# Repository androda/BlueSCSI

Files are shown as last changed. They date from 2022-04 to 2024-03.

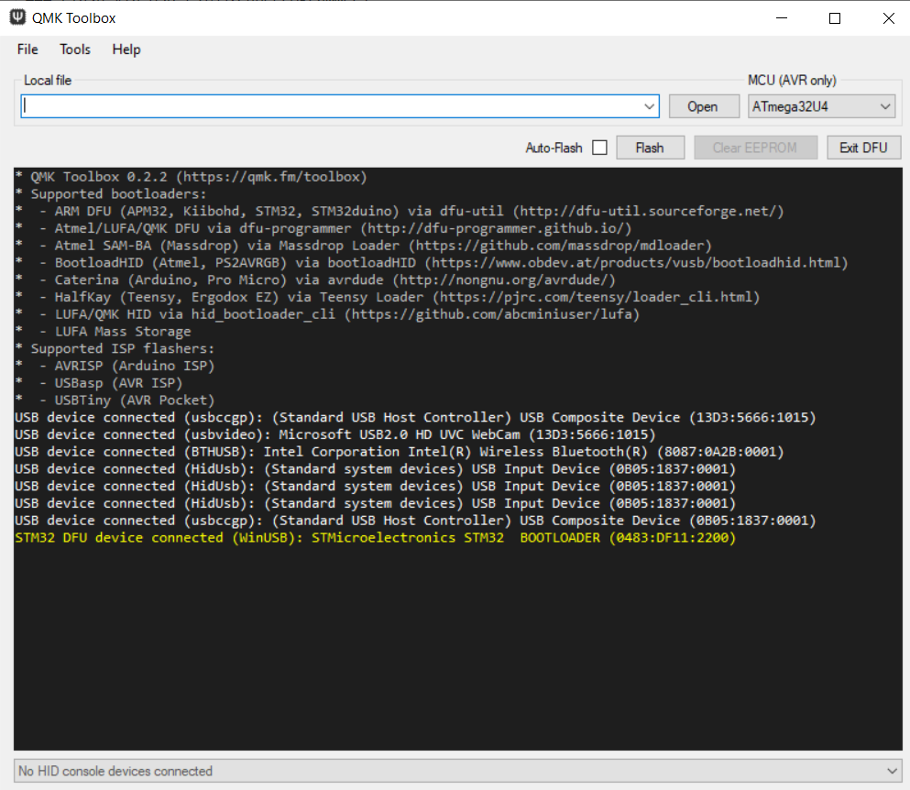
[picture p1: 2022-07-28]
docs/Images/qmk_toolbox_STM32_Detected.PNG

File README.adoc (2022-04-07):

# F4 BlueSCSI
:toc: macro

`F4 BlueSCSI`, ported by https://github.com/androda[androda], is a fork of `BlueSCSI` which targets the STM32F401 and STM32F411 microcontrollers.

toc::[]

### Lineage
F4 BlueSCSI, BlueSCSI, and ArdSCSino are hardware that reproduces SCSI devices (hard disks) with an STM32 Microcontroller.

`BlueSCSI` was created by https://github.com/erichelgeson[erichelgeson]

`ArdSCSino-stm32` was created by https://github.com/ztto/ArdSCSino-stm32[ztto], and is the STM32 version of `ArdSCSino`

`ArdSCSino` was created by https://twitter.com/h_koma2[Tambo (TNB Seisakusho)]

## Discussion
Join us in #bluescsi on https://discord.gg/GKcvtgU7P9[Discord].

## Compatibility and Performance
https://github.com/androda/F4_BlueSCSI/wiki/System-Compatibility-and-Performance[Compatibility and Performance]

## Assembly
Assembly instructions are generally found on my separate site, here: https://androda.work/kit-assembly/
These aren't really assembly instructions either, mostly pictures of the assembled design with tips on which way things should be facing.

## Usage
https://github.com/erichelgeson/BlueSCSI/wiki/Usage[Usage] is intended to be the same as the parent project and will be kept in sync until the blue pill module's flash is all used.  Then F4 will start to diverge.

### Termination
Termination enable / disable is handled differently per board style.  See the instructions for each PCB design.

## Firmware Updates
https://github.com/androda/F4_BlueSCSI/wiki/Flashing-Firmware-Updates[Flashing Firmware Updates]

## Troubleshooting
(to be completed, currently similar to the parent repo - but there are no jumpers on these dev modules.)
https://github.com/erichelgeson/BlueSCSI/wiki/Troubleshooting

## Hardware Versions
Generally speaking, hardware versions follow a naming scheme.

Variant.Maker.Style.Version

For example: {F4.TbA.D.V1}

This is an F4 model from Tech by Androda, D is for Desktop and V1 means first revision.

## Development (Advanced, annoying to set up)
https://github.com/androda/F4_BlueSCSI/tree/main/docs/Dev_Instructions[Dev Instructions]

## Notes

### Building the Code
- Build experience is unfortunately complex due to Maple's STM32F4 compatibility issues

### Making Gerbers for JLCPCB
https://support.jlcpcb.com/article/44-how-to-export-kicad-pcb-to-gerber-files

BlueSCSI(TM) - Eric Helgeson - All rights reserved. - Used with permission

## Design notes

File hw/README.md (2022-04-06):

# F4 and F4Lite Hardware License

* © 2021 - 2022 Tech by Androda, LLC
* All hardware design files, design artifacts, and in general all files provided in the hardware section (/hw/ and below) are licensed Attribution-NonCommercial-ShareAlike 4.0 International (CC BY-NC-SA 4.0)
* https://creativecommons.org/licenses/by-nc-sa/4.0/legalcode

These files are provided AS-IS with no warranty of any kind to the maximum extent allowed by law.

License Explanation:

Hardware:
This license means that you can have these designs produced by the PCB maker of your choice, for your own personal use.
You, the licensee, are not permitted to re-sell the PCBs which are produced using these design and production files.  They are not licensed for sale of any kind, regardless of whether you have 'spares' left over.  Selling them 'at cost' or 'below cost' is also a violation of the license, because those are sales too.

3D Printable Files:
This license allows you to print these printable files yourself, or have them printed for you, for your own personal use.  You, the licensee, are not permitted to re-sell the printed parts which are produced under this license.  They are not licensed for sale of any kind, regardless of whether you made (or had made) more than you needed.  A sale 'at cost' or 'below cost' is still a sale and is a license violation.

All other files:
Seriously, why would you try to sell these?

Alternate Licensing available:
If you would like to produce these hardware designs and printed parts for sale, you are encouraged to contact Tech by Androda, LLC to arrange alternate licensing.  https://androda.work/about/

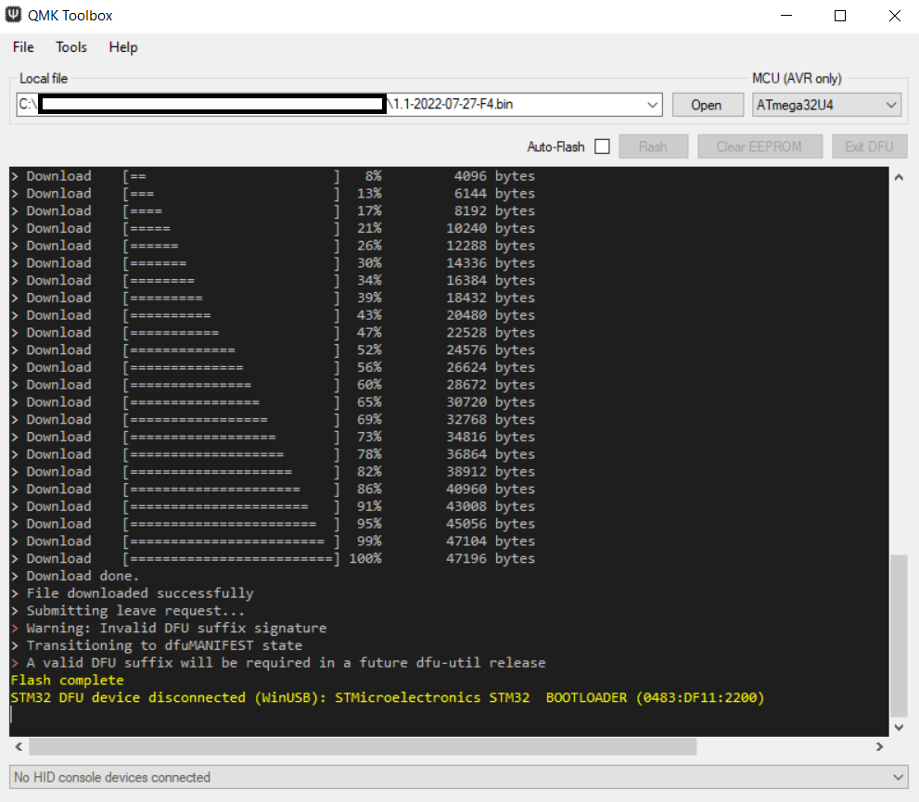
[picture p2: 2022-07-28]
docs/Images/qmk_toolbox_flash_successful.PNG

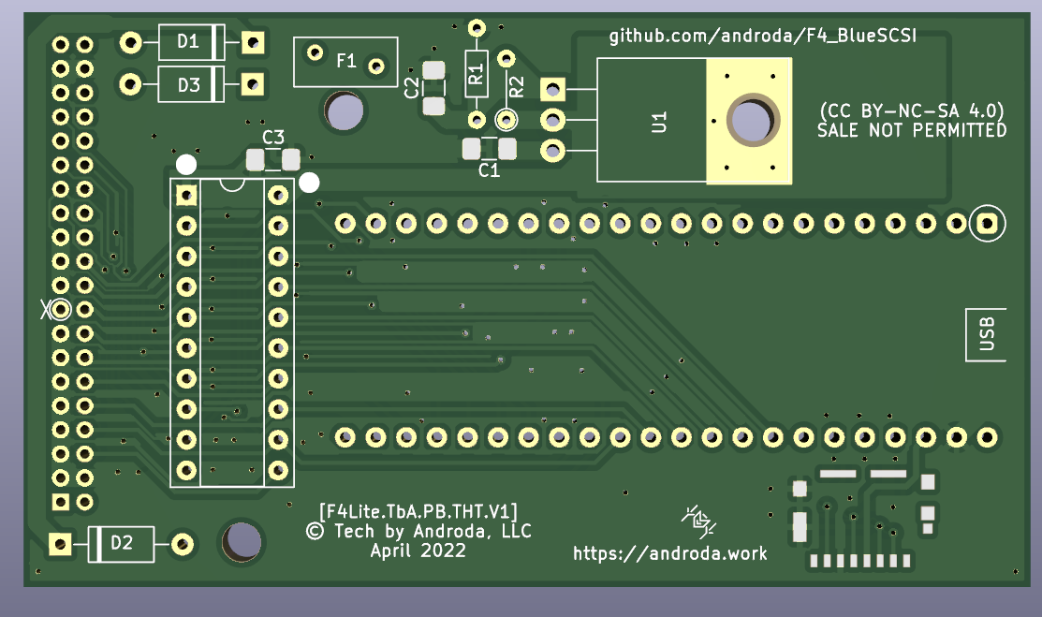
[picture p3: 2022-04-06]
hw/PowerBook/PowerBook_F4Lite_THTV1/TopOfPCB.PNG

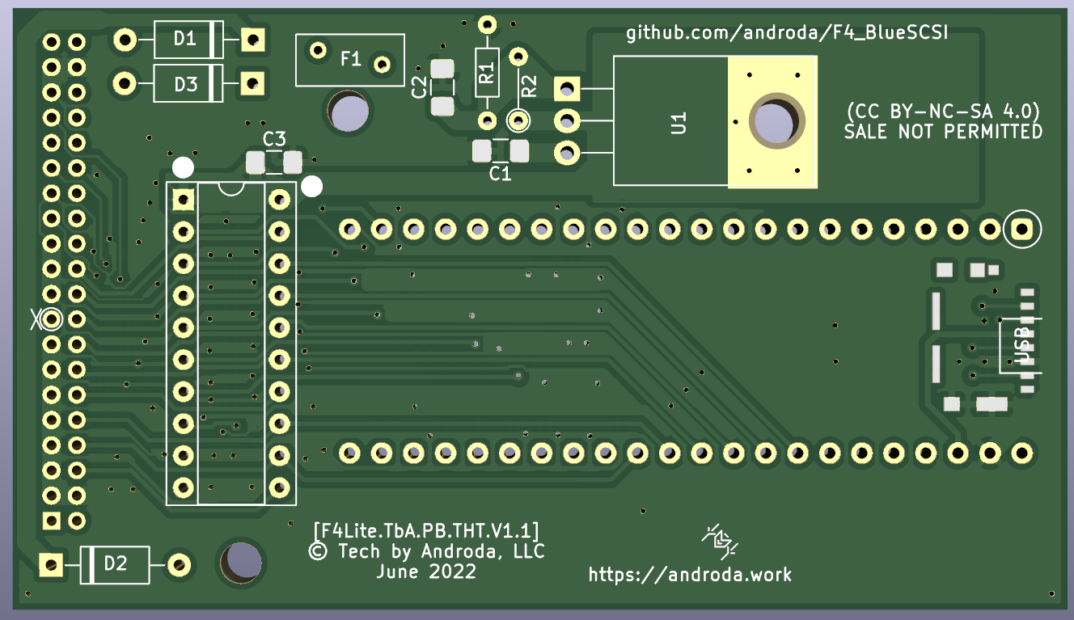
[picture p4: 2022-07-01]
hw/PowerBook/PowerBook_F4Lite_THTV1.1/TopOfPCB.PNG

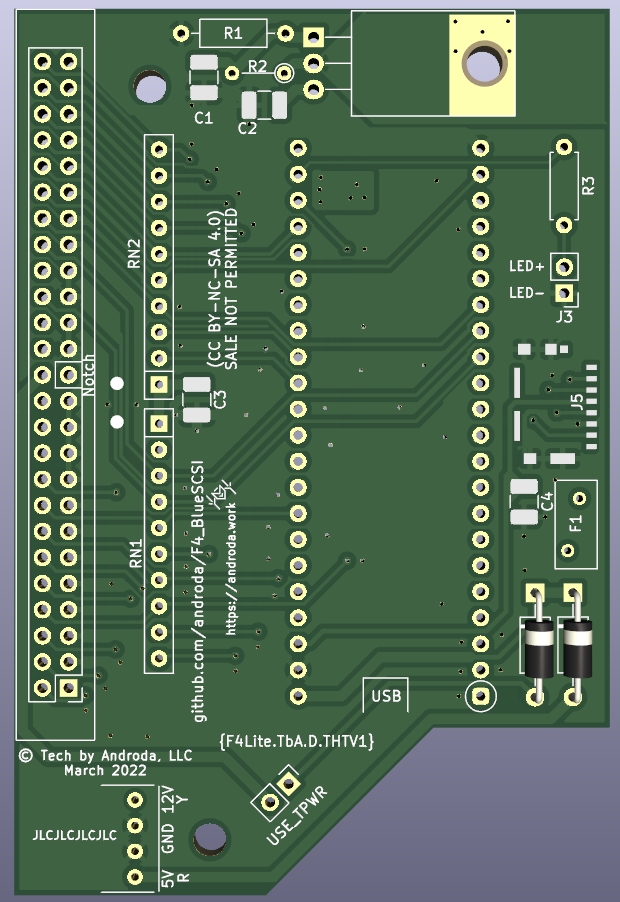
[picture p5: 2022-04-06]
hw/Desktop_50Pin/F4Lite_THTV1/TopofPCB.PNG

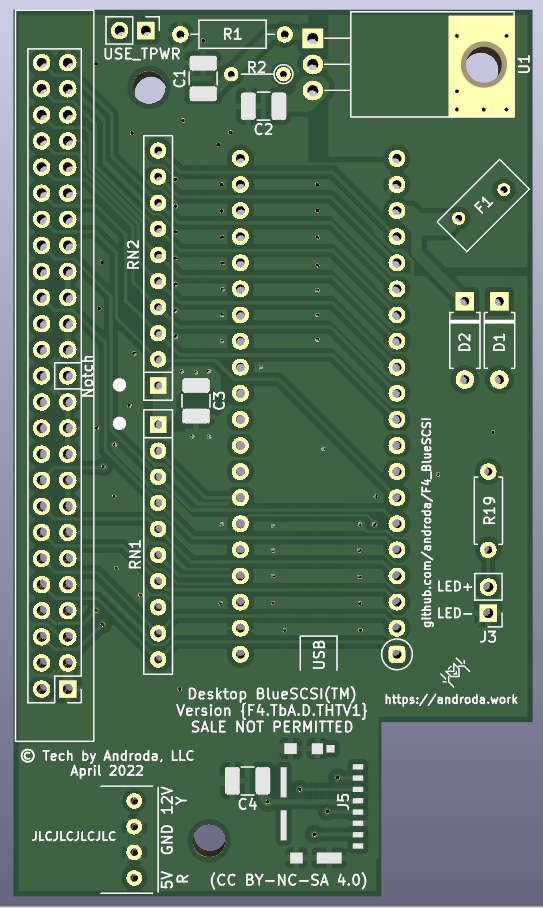
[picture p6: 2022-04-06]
hw/Desktop_50Pin/F4_THTV1/TopOfPCB.PNG

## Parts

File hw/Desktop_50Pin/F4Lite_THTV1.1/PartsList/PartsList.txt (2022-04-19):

Parts List for F4Lite THT V1.1

Through-hole parts:

Some 2.54mm header strip (optional, could hard wire 'USE_TPWR' jumper and hard wire the LED)
A 2.54mm jumper (If using header strip for the USE_TPWR jumper, this is required)
0ZRR0050FF1E fuse, x1
SB130-T diodes, x2 (any schottky with 800mA+ rating ought to be fine)
LD1117V adjustable linear regulator x1
MFS1/4DCT52R1200F 120 ohm resistor for position R2, x1
MFR-25FBF52-154R 154 ohm resistor for position R1, x1
^  These resistor *values* are non-negotiable, but their physical sizing can differ
470 Ohm resistor for LED, x1  (bought on eBay, precision doesn't matter)
4610X-101-111LF 110 ohm resistor network, x2
^ Can grab some 20 pin DIP chip sockets and chop in half to use as sockets for the resistor nets
Berg Floppy connector, TE Connectivity 171826-4
50 pin SCSI connector, or male 2x25 2.54mm header: Must be straight-out only
^ For the SCSI connector, there are a ton of options:
* 3M 30350-6002HB (straight)
* https://www.aliexpress.com/item/4000284180928.html

Microcontroller Module:
STM32F401 "Green Pill", this is the one you're looking for: https://stm32-base.org/boards/STM32F401CCU6-STM32-Mini-F401
* Search Amazon or eBay for "STM32F401"
* https://www.aliexpress.com/item/1005001639712812.html

Surface-Mount parts:
Three 1206 size 22uF capacitors, 10+ volt rating (higher voltage rating is better, I used 25V)
Molex 105162-0001 MicroSD Card Slot
Four 0805 size 4.7uF capacitors, 10+ volt rating (higher voltage rating is better, I do 16+)
* Generally speaking any value from 0.1uF to 4.7uF is fine for these.  They are just for extra decoupling.

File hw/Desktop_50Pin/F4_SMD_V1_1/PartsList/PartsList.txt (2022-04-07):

Parts List for F4 SMD V1.1

Through-hole parts:
Some 2.54mm header strip (optional, could hard wire 'USE_TPWR' jumper and hard wire the LED)
A 2.54mm jumper (If using header strip for the USE_TPWR jumper, this is required)
Berg Floppy connector, TE Connectivity 171826-4
50 pin SCSI connector, male 2x25 2.54mm header - can be straight-out or right-angle as long as the notch is in the right place.
^ For the SCSI connector, there are a ton of options:
* 3M 30350-6002HB (straight)
* 3M 30350-5002HB (right angle)
* https://www.aliexpress.com/item/4000284180928.html

Microcontroller Module:
STM32F411 "Black Pill" (note that there are two versions of this design, one using an F411 and one with an F401 - F411 is the correct one)
This is the one you want: https://stm32-base.org/boards/STM32F401CEU6-WeAct-Black-Pill-V3.0
^ Note that this page says it's an F401, but the official store (aliexpress link below) shows an F411.
* Search Amazon or eBay for "STM32F411" 
* https://www.aliexpress.com/item/1005001456186625.html

Surface-Mount parts:
Two 1206 size 22uF capacitors, 10+ volt rating (higher voltage rating is better, I used 25V)
One 0805 size 4.8uF capacitor, similar voltage rating as ^
Three SOD-123F Schottky Diodes, 800+ mA continuous current rating
Two 0805 size 500mA-hold rated PTC Fuses
Eighteen 0603 size 110 ohm resistors
One 2.85v rated 1117 linear regulator in SOT-223 package
Two SN74CBTD3861DBQR bus switches
Molex 105162-0001 MicroSD Card Slot

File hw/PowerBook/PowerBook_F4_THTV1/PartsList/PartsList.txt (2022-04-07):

Parts List for PowerBook F4 THT V1

Through-hole parts:

0ZRR0050FF1E fuse, x1
SB130-T diodes, x3 (any schottky with 800mA+ rating ought to be fine)
LD1117V adjustable linear regulator x1
MFS1/4DCT52R1200F 120 ohm resistor for position R2, x1
MFR-25FBF52-154R 154 ohm resistor for position R1, x1
^  These resistor *values* are non-negotiable, but their physical sizing can differ
4610X-101-102LF 1000 ohm resistor network, x2
^ Can grab some 20 pin DIP chip sockets and chop in half to use as sockets for the resistor nets
40 Pin PowerBook SCSI connector
* Harwin M22-2042005
* 2x20 2.0mm two-row connectors have been hard to find.  But 2x40 are somewhat common, and can be cut in half with an exacto knife.
* https://www.aliexpress.com/item/2051375493.html

Microcontroller Module:
STM32F411 "Black Pill" (note that there are two versions of this design, one using an F411 and one with an F401 - F411 is the correct one)
This is the one you want: https://stm32-base.org/boards/STM32F401CEU6-WeAct-Black-Pill-V3.0
^ Note that this page says it's an F401, but the official store (aliexpress link below) shows an F411.
* Search Amazon or eBay for "STM32F411" 
* https://www.aliexpress.com/item/1005001456186625.html

Surface-Mount parts:
Three 1206 size 22uF capacitors, 10+ volt rating (higher voltage rating is better, I used 25V)
Molex 105162-0001 MicroSD Card Slot

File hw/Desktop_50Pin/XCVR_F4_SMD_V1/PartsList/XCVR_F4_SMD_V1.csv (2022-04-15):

Id | Designator | Quantity | Part
1 | J3 | 1 | SCSI 50 Pin Connector, 2x25 2.54mm spacing male header
2 | R6,R4,R5,R10,R7,R8,R1,R11,R9,R3,R2,R18,R17,R16,R15,R14,R13,R12 | 18 | 0603 SMD Resistor, 110 Ohm
3 | J4 | 1 | Berg Floppy Connector, TE Connectivity 171826-4
4 | C1,C2 | 2 | 1206 SMD 22uF Capacitor, 10v+
5 | U3 | 1 | AMS1117-2.85
6 | U1, U2 | 2 | SN74CBTD3861DBQR
7 | F1 | 1 | 0ZRR0050FF1E
8 | C3,C9,C10,C11,C12 | 5 | 0805 SMD 4.7uF Capacitor, 10v+
10 | U4,U5 | 2 | SN74LVT162245ADGGR
11 | C4,C5,C6,C7,C8 | 5 | 0805 SMD 0.1uF Capacitor, 10v+
12 | R19 | 1 | 0805 SMD 10k resistor
13 | J1 | 1 | 1x2 male header
14 | R21 | 1 | 0805 SMD Resistor, 470 Ohm
15 | SD1 | 1 | SOFNG SD-001
16 | D1,D2 | 2 | SS14 SMA Diode
17 | J2 | 1 | 1x3 male header
18 | U6 | 1 | Black STM32F411 Dev Board

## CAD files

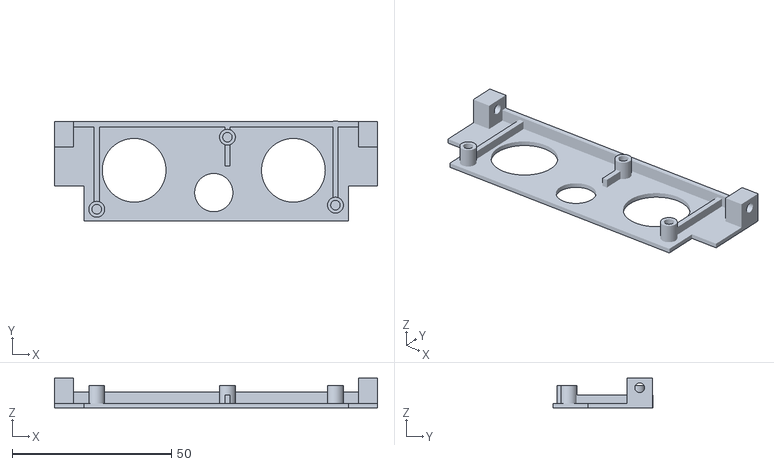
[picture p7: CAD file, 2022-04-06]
hw/Desktop_50Pin/F4_SMD_V1_1/F4_V1_DesktopMountingBracket.stl
101.4 x 31.5 x 9.40

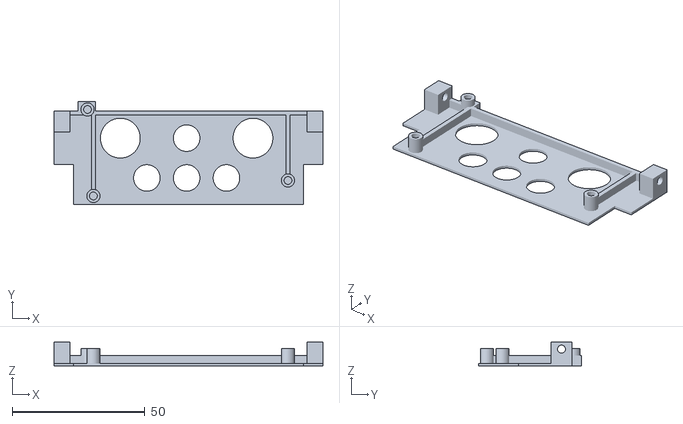
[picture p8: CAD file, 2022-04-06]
hw/Desktop_50Pin/F4_THTV1/MountingBracket.stl
101.4 x 38.8 x 9.00

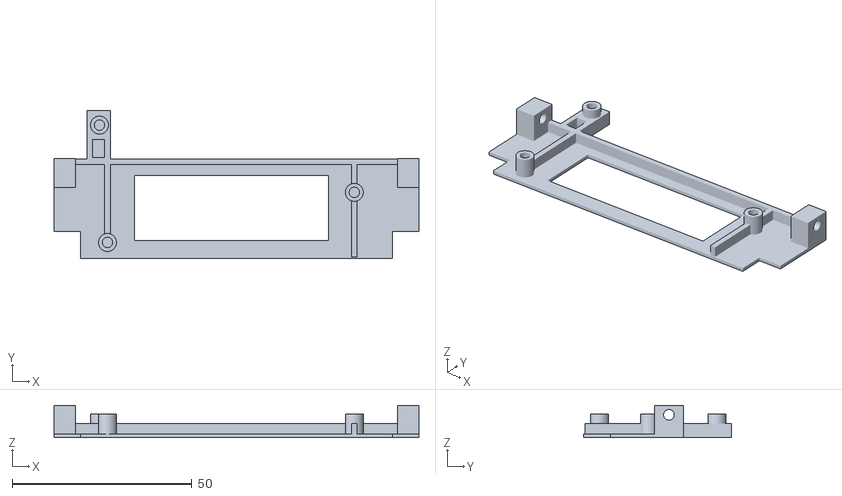
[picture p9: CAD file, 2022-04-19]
hw/Desktop_50Pin/F4Lite_THTV1.1/MountingBracket.stl
101.4 x 41.0 x 9.00

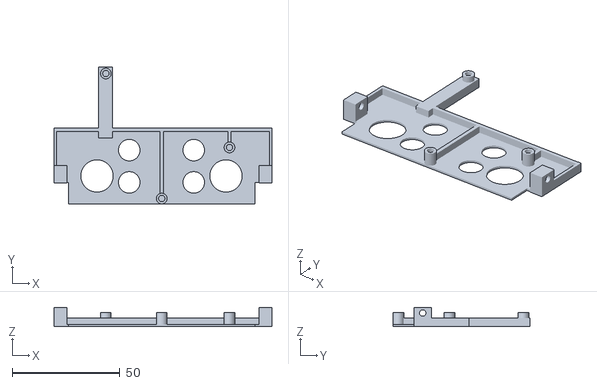
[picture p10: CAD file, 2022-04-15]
hw/Desktop_50Pin/XCVR_F4_SMD_V1/MountingBracket.stl
101.4 x 63.6 x 9.00

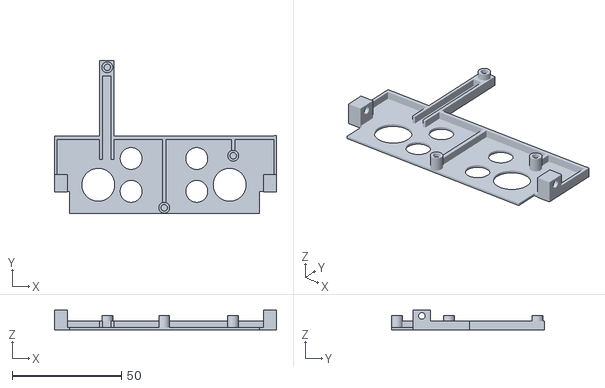
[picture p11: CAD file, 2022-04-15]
hw/Desktop_50Pin/XCVR_F4Lite_SMD_V1/MountingBracket.stl
101.4 x 69.7 x 9.00

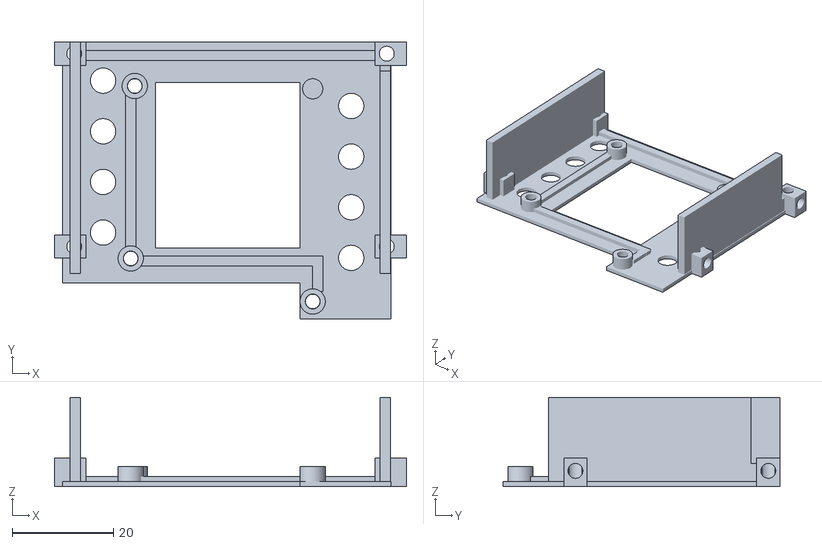
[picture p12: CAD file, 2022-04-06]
hw/PowerBook/PowerBook_F4Lite_THTV1.2/PBMountingBracket_THTV1_1.stl
69.5 x 54.7 x 17.6

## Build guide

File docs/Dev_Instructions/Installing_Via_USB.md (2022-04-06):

# Installing F4 BlueSCSI Binaries via USB

**Important note: These instructions haven't always worked for me.  In a few cases, the firmware updates happily over USB, but most of the time - hard nope, STLink only.  Sadly low success rate.** 

You need: A USB-C cable.  That's it.

1. Remove the SD card from your BlueSCSI unit
2. Install STM32CubeProgrammer
   - They want you to give them your email address.  Just use temp-mail.org to get a temp one for the download
3. Model-specific instructions:
   1. For F4: Hold down the "Boot0" button and plug the USB cable into your computer
   2. For F4Lite, switch the DIP position 3 to 'on' before plugging into USB
      - Make sure to switch back to 'off' after programming or you'll be confused why it isn't working at all
4. Note that there should be only the red power LED lit.  If there's blinking of any kind from the other LED, stop and try again
5. Start STM32CubeProgrammer
6. In the top right, switch from ST-Link to USB
7. Your dev board should appear when you click the little 'refresh' circle
   - If there's flashing from the activity LED, go back to 3 and run through the hardware setup again.  Only the red power LED should be on.
   - If your dev board does not appear, despite following these steps - sorry, it's not going to work.  I am unable to determine why this happens.
8. If your dev board does appear, great - continue on
9. Click the 'Open File' tab, select your firmware, and click the blue 'Download' button that appears over on the right
10. Hopefully this works for you, because otherwise you need to buy an STLink V2 clone (yes, clone) for programming updated firmware.

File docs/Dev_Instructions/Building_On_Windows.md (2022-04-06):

# Building F4 BlueSCSI From Source On Windows

These instructions are targeted at Windows, because that's what I used to originally do the port work.

1. Install Visual C++ 2010 redistributable
   - Download and install the Visual C++ 2010 Redistributables (*both* x86 and x64) from here: https://www.microsoft.com/en-us/download/details.aspx?id=26999
2. Download the F4 BlueSCSI code from: https://github.com/androda/F4_BlueSCSI
3. Install Arduino IDE 1.8.latest
4. Go to https://github.com/androda/Arduino_STM32 and download the source code zip. (this repo was forked just to ensure I can curate new changes for errors)
5. Extract the Arduino_STM32_F4-master.zip zip file you downloaded.
   - Open the folder and you might see another folder named the same thing.
   - Keep drilling down until you see the folders named drivers, STM32F1, STM32F4, etc.  Keep this folder open.
6. Open Arduino IDE
   - Go to Board Manager and install "Arduino SAM Boards" (1.6.12 has been used here)
   - Open Preferences and find your Sketchbook Location.  Mine was "C:\Users\Username\Documents\Arduino"
7. Close Arduino IDE and navigate to that Sketchbook Location
   - In this folder you will probably only see a folder named 'libraries'.
   - Create a sibling folder (sibling to libraries) named 'hardware'.
   - Inside the hardware folder, create another new folder named 'Arduino_STM32'.
   - Move (or copy) everything from the previous folder (which you kept open, right?) into this Arduino_STM32 folder.
8. Reopen Arduino IDE and you will find under the Boards menu that there are choices for STM32F103, and others.
   - In the board dropdown menu, select "Blackpiill STM32F401CCU6"
   - Also in this dropdown menu select Optimize: "Faster (-O2)"
     - If you don't select this, your resulting bluescsi program will run slower
9. In the Library Manager, install SDFat (by Bill Greiman) version 2.0.6
10. If you now open the F4_BlueSCSI.ino file and try to build... it will fail.  SdSpiSTM32.cpp will appear near the end of the errors, something about control reaching the end of a non-void function.
11. Now the really obtuse part.  We get to modify SDFat.
    - Back in your Arduino Sketchbook folder, open libraries/SdFat/src/SpiDriver/SdSpiSTM32.cpp in a text editor
    - Modify line 59 to remove the word "return" and add a new line underneath saying "return 0;"
12. Keep your text editor open, and open the F4_BlueSCSI.ino arduino project.  If you build now, it should work just fine.
13. Now for another obtuse part: Setting the clock speed.  The difference between STM32F401 (F4 Lite) and STM32F411 (full F4) is nothing more than clock speed.  F4Lite runs at 84MHz, and full F4 runs at 96MHz.
    - To change this, in your arduino sketchbook folder open the file hardware/Arduino_STM32/STM32F4/variants.blackpill_f401/blackpill_f401.h
    - In here you will see a line that #defines CLOCK_SPEED_MHZ.  You can simply change this to 96 for the F411.
    - I need to make a new build target for the maple framework, but every time I've tried there has been some sort of error.
    - F4Lite (F401) reaches 1800k read and 1300k write on my beige g3.  Full F4 (F411) reaches 1800k read and 1500k write.
14. Open the F4_BlueSCSI.ino project file.
15. The code should build successfully!
16. STLink V2 hardware setup
    - Download STLink drivers from: https://www.st.com/en/development-tools/stsw-link009.html
    - They reeeeeally want you to register or at least give them your email address to download this software.  Just use temp-mail.org to get a temporary disposable email and use the download link they email to the temporary email address.
    - Extract the zip and run 'dpinst_amd64.exe'
    - Optionally, use stsw-link-007.  This is a firmware update to make the stlink v2 device compatible with the new stm32cubeprogrammer.  Only necessary if you intend to export binaries from Arduino IDE and program separately.
17. Now you need an STLink V2 clone. 
    - Yes, I said clone - not the actual STLink V2 because they tend not to work for some reason.
    - Get one of the USB stick looking ones, hook up the pins (SWclk, SWdio, 3.3v, gnd) and you can upload from the Arduino IDE straight to your STM32F4 dev board.
18. Connect the STLink to the module via the four necesssary pins (3.3v, GND, SWD, SWCLK) and click the upload button in Arduino IDE.
    - Theoretically, all is well and programming succeeds.
    - If your STLink is not recognized, check the device manager to be sure it appears there as an STLink and not 'unknown device'.
    - Try unplugging and re-plugging the ST-Link.  Some of these clones have issues from time to time.

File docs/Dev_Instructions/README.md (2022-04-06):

F4 BlueSCSI Documentation © 2021-2022 by Tech by Androda, LLC are licensed: Attribution-NonCommercial-ShareAlike 4.0 International (CC BY-NC-SA 4.0)
https://creativecommons.org/licenses/by-nc-sa/4.0/legalcode

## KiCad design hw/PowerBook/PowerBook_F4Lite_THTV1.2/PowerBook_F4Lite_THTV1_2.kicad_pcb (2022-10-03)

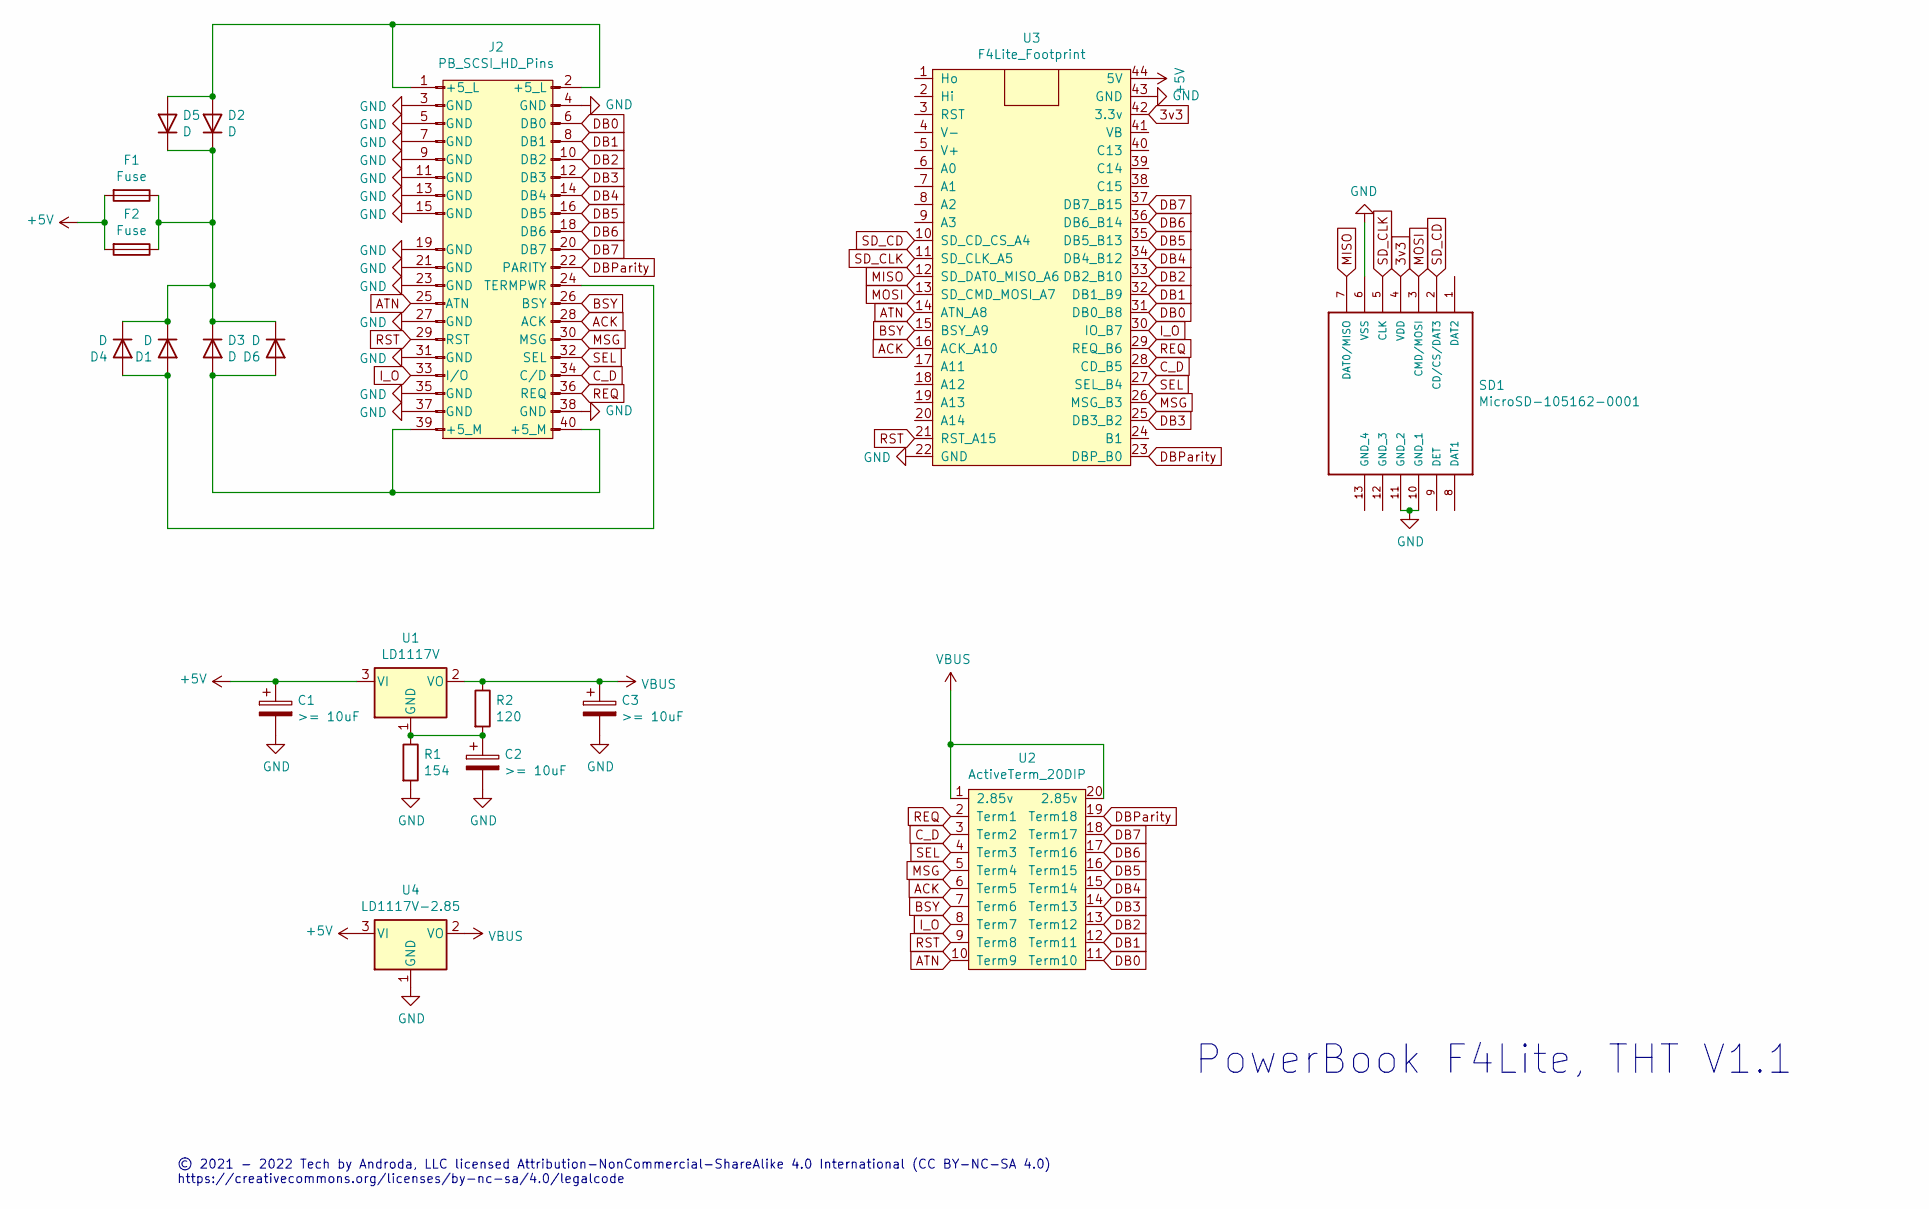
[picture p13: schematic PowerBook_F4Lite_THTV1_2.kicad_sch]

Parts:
C1, C2, C3: >= 10uF; C_1206_3216Metric_Pad1.42x1.75mm_HandSolder
D1, D2, D3: D; D_A-405_P10.16mm_Horizontal
D4, D5, D6: D; D_SMA
F1: Fuse; Fuse_BelFuse_0ZRE0005FF_L8.3mm_W3.8mm
F2: Fuse; Fuse_0805_2012Metric_Pad1.15x1.40mm_HandSolder
J2: PB_SCSI_HD_Pins; PowerBook_SCSI_40Pin_UpsideDown
R1: 154; R_Axial_DIN0204_L3.6mm_D1.6mm_P7.62mm_Horizontal
R2: 120; R_Axial_DIN0204_L3.6mm_D1.6mm_P5.08mm_Vertical
SD1: MicroSD-105162-0001; microsd_molex_1051620001; MANUFACTURER_PART_NUMBER 105162-0001; MOUSER_PART_NUMBER 538-105162-0001
U1: LD1117V; TO-220-3_Horizontal_TabDown
U2: ActiveTerm_20DIP; DIP-20_W7.62mm_Socket
U3: F4Lite_Footprint
U4: LD1117V-2.85; SOT-223-3_TabPin2

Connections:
3v3: SD1.4 (VDD), U3.42 (3.3v)
+5V: C1.1, F1.2, F2.2, U1.3 (VI), U3.44 (5V), U4.3 (VI)
ACK: J2.28 (ACK), U2.6 (Term5), U3.16 (ACK_A10)
ATN: J2.25 (ATN), U2.10 (Term9), U3.14 (ATN_A8)
BSY: J2.26 (BSY), U2.7 (Term6), U3.15 (BSY_A9)
C_D: J2.34 (C/D), U2.3 (Term2), U3.28 (CD_B5)
DB0: J2.6 (DB0), U2.11 (Term10), U3.31 (DB0_B8)
DB1: J2.8 (DB1), U2.12 (Term11), U3.32 (DB1_B9)
DB2: J2.10 (DB2), U2.13 (Term12), U3.33 (DB2_B10)
DB3: J2.12 (DB3), U2.14 (Term13), U3.25 (DB3_B2)
DB4: J2.14 (DB4), U2.15 (Term14), U3.34 (DB4_B12)
DB5: J2.16 (DB5), U2.16 (Term15), U3.35 (DB5_B13)
DB6: J2.18 (DB6), U2.17 (Term16), U3.36 (DB6_B14)
DB7: J2.20 (DB7), U2.18 (Term17), U3.37 (DB7_B15)
DBParity: J2.22 (PARITY), U2.19 (Term18), U3.23 (DBP_B0)
GND: C1.2, C2.2, C3.2, J2.3 (GND), J2.4 (GND), J2.5 (GND), J2.7 (GND), J2.9 (GND), J2.11 (GND), J2.13 (GND), J2.15 (GND), J2.19 (GND), J2.21 (GND), J2.23 (GND), J2.27 (GND), J2.31 (GND), J2.35 (GND), J2.37 (GND), J2.38 (GND), R1.2, SD1.6 (VSS), SD1.10 (GND_1), SD1.11 (GND_2), U3.22 (GND), U3.43 (GND), U4.1 (GND)
I_O: J2.33 (I/O), U2.8 (Term7), U3.30 (IO_B7)
MISO: SD1.7 (DAT0/MISO), U3.12 (SD_DAT0_MISO_A6)
MOSI: SD1.3 (CMD/MOSI), U3.13 (SD_CMD_MOSI_A7)
MSG: J2.30 (MSG), U2.5 (Term4), U3.26 (MSG_B3)
unnamed: C2.1, R1.1, R2.2, U1.1 (GND)
unnamed: D1.1 (K), D2.1 (K), D3.1 (K), D4.1 (K), D5.1 (K), D6.1 (K), F1.1, F2.1
unnamed: D1.2 (A), D4.2 (A), J2.24 (TERMPWR)
unnamed: D2.2 (A), D5.2 (A), J2.1 (+5_L), J2.2 (+5_L)
unnamed: D3.2 (A), D6.2 (A), J2.39 (+5_M), J2.40 (+5_M)
REQ: J2.36 (REQ), U2.2 (Term1), U3.29 (REQ_B6)
RST: J2.29 (RST), U2.9 (Term8), U3.21 (RST_A15)
SD_CD: SD1.2 (CD/CS/DAT3), U3.10 (SD_CD_CS_A4)
SD_CLK: SD1.5 (CLK), U3.11 (SD_CLK_A5)
SEL: J2.32 (SEL), U2.4 (Term3), U3.27 (SEL_B4)
VBUS: C3.1, R2.1, U1.2 (VO), U2.1 (2.85v), U2.20 (2.85v), U4.2 (VO)

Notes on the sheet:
© 2021 - 2022 Tech by Androda, LLC licensed Attribution-NonCommercial-ShareAlike 4.0 International (CC BY-NC-SA 4.0) https://creativecommons.org/licenses/by-nc-sa/4.0/legalcode
PowerBook F4Lite, THT V1.1

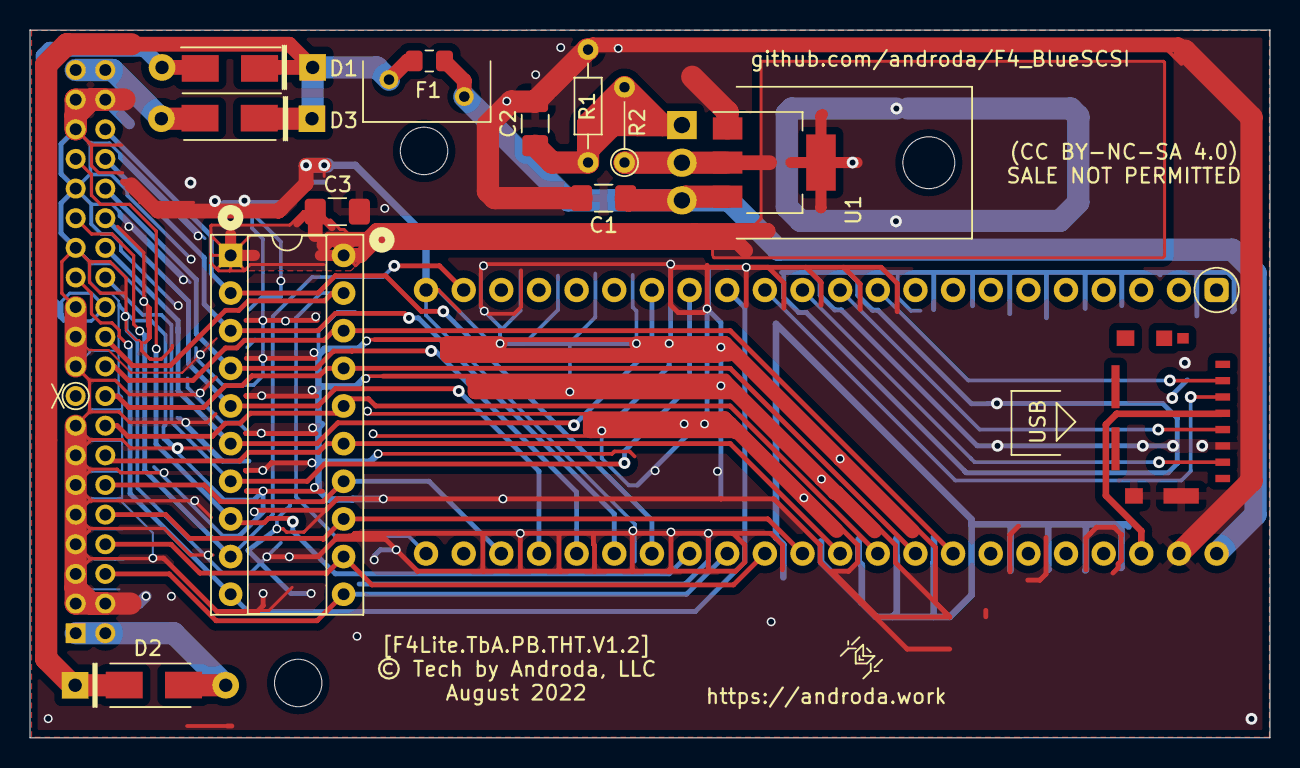
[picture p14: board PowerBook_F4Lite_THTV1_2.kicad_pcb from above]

Board: 2 copper layers, 83.7 x 47.8 mm, 19 parts (0 on the bottom side), 31 nets.

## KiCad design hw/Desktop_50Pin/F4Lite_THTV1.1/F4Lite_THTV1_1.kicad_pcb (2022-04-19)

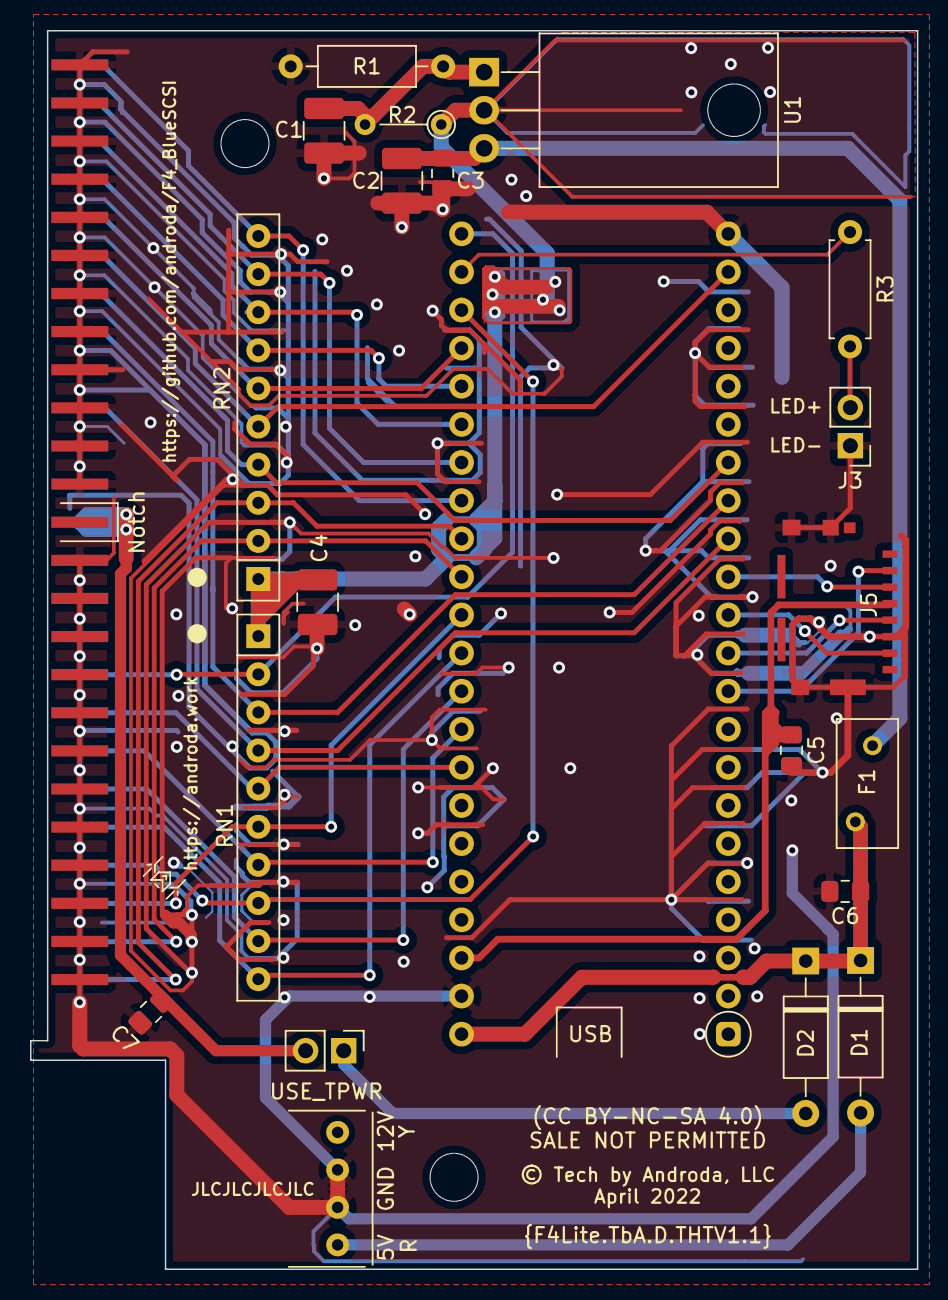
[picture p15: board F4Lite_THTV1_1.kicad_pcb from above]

Board: 2 copper layers, 59.1 x 82.5 mm, 22 parts (0 on the bottom side), 33 nets.

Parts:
C1, C2, C4: 10uF; C_1210_3225Metric_Pad1.42x2.65mm_HandSolder
C3: 0.1uF; C_0805_2012Metric_Pad1.15x1.40mm_HandSolder
C5, C6, C7: 4.7uF; C_0805_2012Metric_Pad1.15x1.40mm_HandSolder
D1, D2: D; D_A-405_P10.16mm_Horizontal
F1: Polyfuse; Fuse_BelFuse_0ZRE0005FF_L8.3mm_W3.8mm
J1, J3: Conn_01x02_Male; PinHeader_1x02_P2.54mm_Vertical
J2: BergFloppy; BergFloppy_RightAngle
J4: SCSI_50Pin; SCSI50_EdgeConn
J5: MicroSD-105162-0001; microsd_molex_1051620001
R1: 154; R_Axial_DIN0207_L6.3mm_D2.5mm_P10.16mm_Horizontal
R2: 120; R_Axial_DIN0204_L3.6mm_D1.6mm_P5.08mm_Vertical
R3: R; R_Axial_DIN0207_L6.3mm_D2.5mm_P7.62mm_Horizontal
RN1, RN2: R_Network09; R_Array_SIP10
U1: AMS1117CD-2.85; TO-220-3_Horizontal_TabDown
U2: GreenSCSI_F401

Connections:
+2V8: C4.1, R2.1, RN1.1, RN2.1, U1.2
+3V3: C5.1, J5.4, U2.42
+5F: C2.1, C3.1, F1.2, U1.3
+5V: C7.1, J1.2, J4.26
+5VP: C6.1, D1.1, D2.1, F1.1, U2.44
ACK: J4.38, RN2.4, U2.16
ATN: J4.32, RN1.4, U2.14
BSY: J4.36, RN1.3, U2.15
CD: J4.46, RN2.8, U2.28
DB0: J4.2, RN2.3, U2.31
DB1: J4.4, RN2.2, U2.32
DB2: J4.6, RN1.6, U2.33
DB3: J4.8, RN1.8, U2.25
DB4: J4.10, RN1.10, U2.34
DB5: J4.12, RN1.9, U2.35
DB6: J4.14, RN1.7, U2.36
DB7: J4.16, RN1.5, U2.37
DBP: J4.18, RN1.2, U2.23
GND: C1.2, C2.2, C3.2, C4.2, C5.2, C6.2, C7.2, J2.2, J2.3, J3.1, J4.1, J4.3, J4.5, J4.7, J4.9, J4.11, J4.13, J4.15, J4.17, J4.19, J4.21, J4.23, J4.27, J4.29, J4.31, J4.33, J4.35, J4.37, J4.39, J4.41, J4.43, J4.45, J4.47, J4.49, J5.6, J5.10, J5.11, J5.12, J5.13, R1.2, U2.22, U2.43
IO: J4.50, RN2.10, U2.30
MSG: J4.42, RN2.6, U2.26
unnamed: C1.1, R1.1, R2.2, U1.1
unnamed: D1.2, J2.1
unnamed: D2.2, J1.1
unnamed: J3.2, R3.2
unnamed: R3.1, U2.24
REQ: J4.48, RN2.9, U2.29
RST: J4.40, RN2.5, U2.21
SD_CLK: J5.5, U2.11
SD_CS: J5.2, U2.10
SD_MISO: J5.7, U2.12
SD_MOSI: J5.3, U2.13
SEL: J4.44, RN2.7, U2.27

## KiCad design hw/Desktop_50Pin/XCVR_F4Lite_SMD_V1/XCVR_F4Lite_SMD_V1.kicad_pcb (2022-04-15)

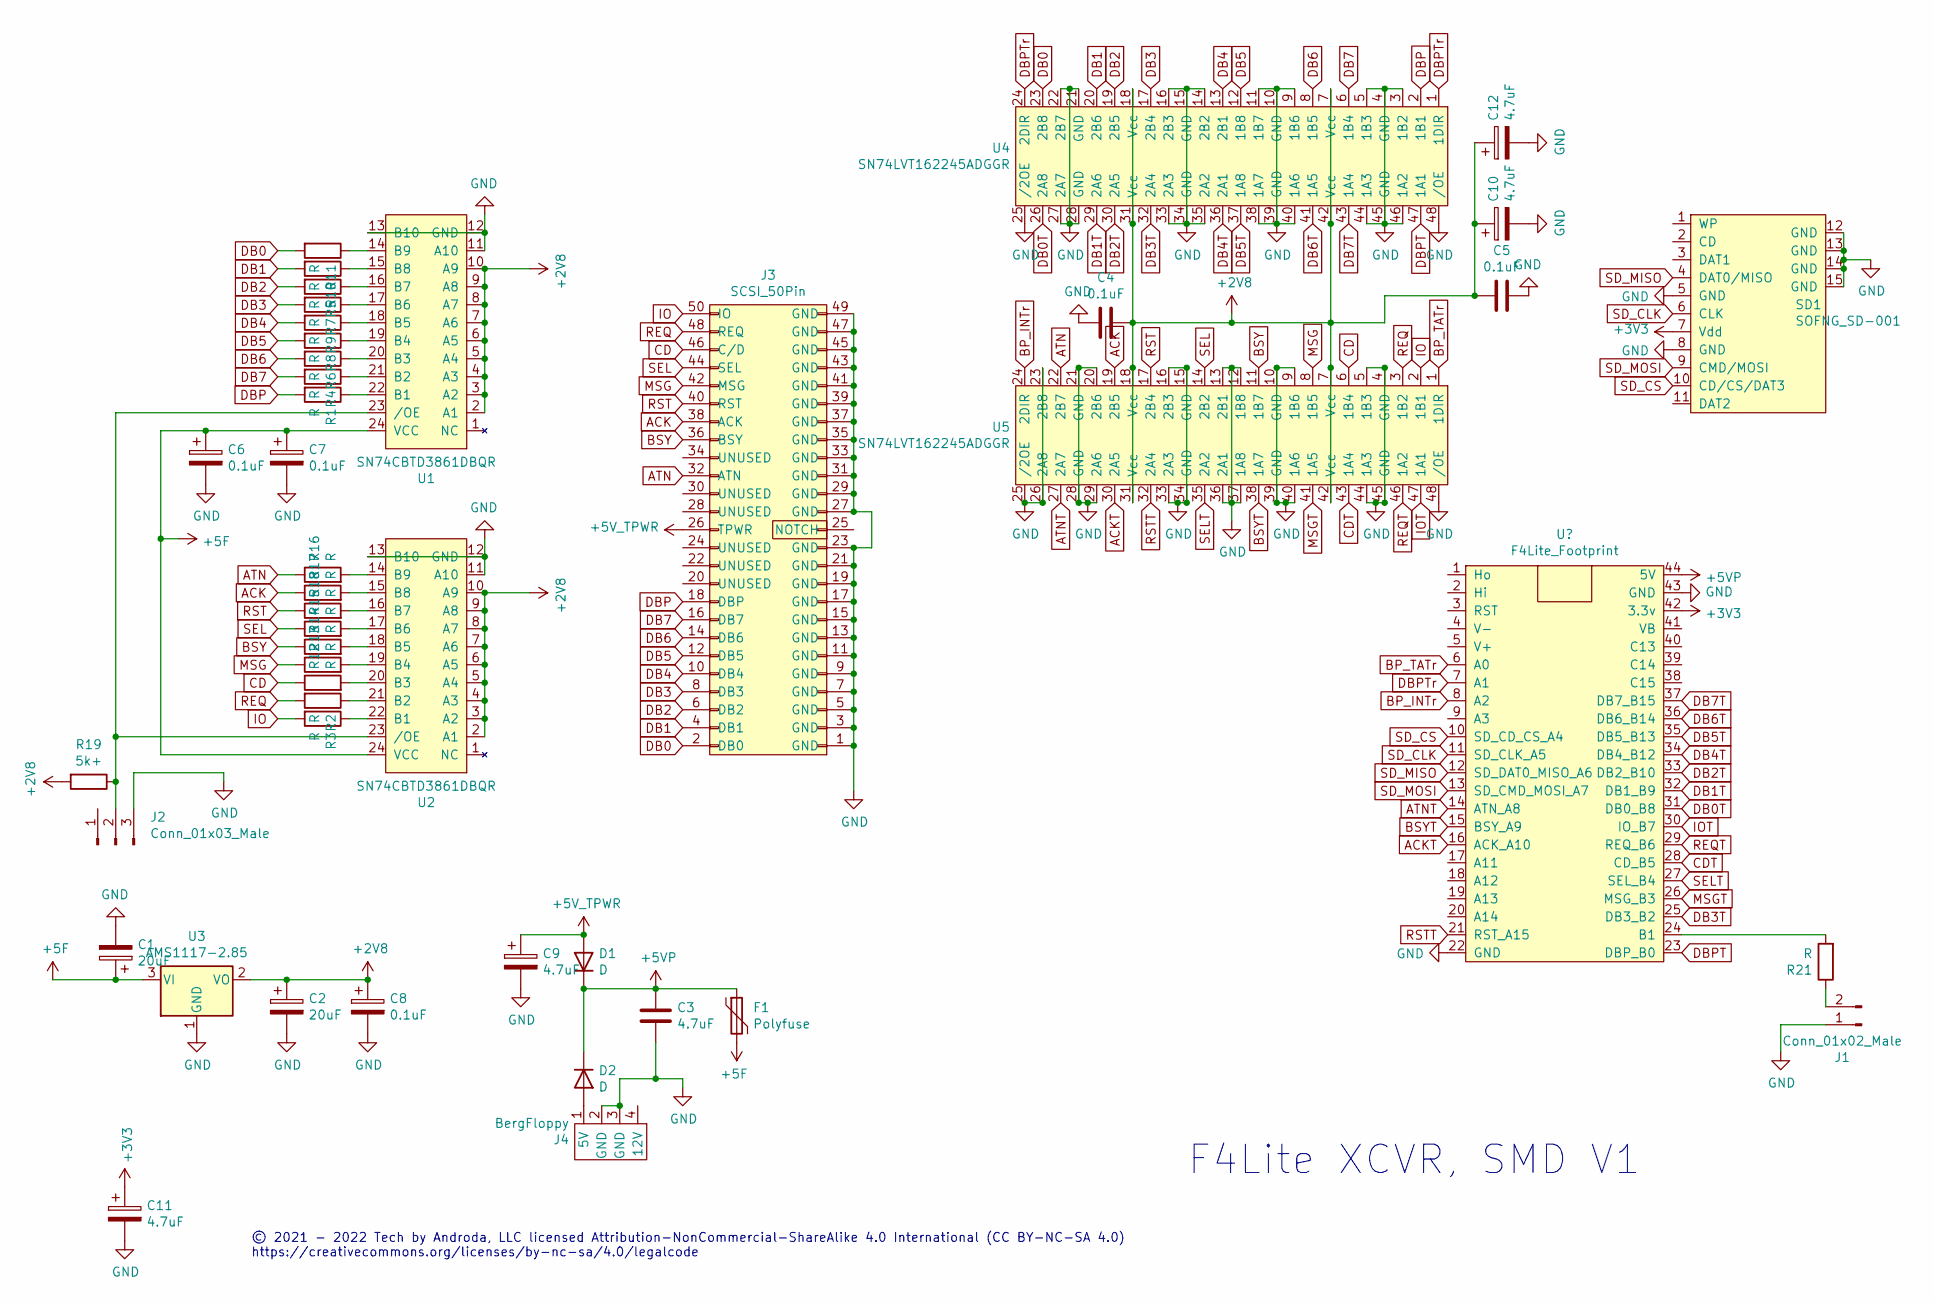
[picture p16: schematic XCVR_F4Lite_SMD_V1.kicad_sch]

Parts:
C1, C2: 20uF; C_1206_3216Metric_Pad1.42x1.75mm_HandSolder
C3, C9, C10, C11, C12: 4.7uF; C_0805_2012Metric_Pad1.15x1.40mm_HandSolder
C4, C5, C6, C7, C8: 0.1uF; C_0805_2012Metric_Pad1.15x1.40mm_HandSolder
D1, D2: D; D_SMA
F1: Polyfuse; Fuse_BelFuse_0ZRE0005FF_L8.3mm_W3.8mm
J1: Conn_01x02_Male; PinHeader_1x02_P2.54mm_Vertical
J2: Conn_01x03_Male; PinHeader_1x03_P2.54mm_Vertical
J3: SCSI_50Pin; SCSI50_EdgeConn
J4: BergFloppy; BergFloppy_RightAngle
R1, R2, R3, R4, R5, R6, R7, R8, R9, R10, R11, R12, R13, R14, R15, R16, R17, R18: R; R_0603_1608Metric_Pad1.05x0.95mm_HandSolder
R19: 5k+; R_0805_2012Metric_Pad1.15x1.40mm_HandSolder
R21: R; R_0805_2012Metric_Pad1.15x1.40mm_HandSolder
SD1: SOFNG_SD-001
U1, U2: SN74CBTD3861DBQR; SSOP-24_3.9x8.7mm_P0.635mm
U3: AMS1117-2.85; SOT-223-3_TabPin2
U4, U5: SN74LVT162245ADGGR; TSSOP-48_6.1x12.5mm_P0.5mm

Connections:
+2V8: C2.1, C4.1, C5.1, C8.1, C10.1, C12.1, R19.2, U1.2 (A1), U1.3 (A2), U1.4 (A3), U1.5 (A4), U1.6 (A5), U1.7 (A6), U1.8 (A7), U1.9 (A8), U1.10 (A9), U2.2 (A1), U2.3 (A2), U2.4 (A3), U2.5 (A4), U2.6 (A5), U2.7 (A6), U2.8 (A7), U2.9 (A8), U2.10 (A9), U3.2 (VO), U4.7 (Vcc), U4.18 (Vcc), U4.31 (Vcc), U4.42 (Vcc), U5.7 (Vcc), U5.18 (Vcc), U5.31 (Vcc), U5.42 (Vcc)
+3V3: C11.1, SD1.7 (Vdd); also elsewhere on the board
+5F: C1.1, C6.1, C7.1, F1.2, U1.24 (VCC), U2.24 (VCC), U3.3 (VI)
+5V: C9.1, D1.2 (A), J3.26 (TPWR)
+5VP: C3.1, D1.1 (K), D2.1 (K), F1.1; also elsewhere on the board
ACK: J3.38 (ACK), R17.1, U5.19 (2B5)
ACKT: U5.30 (2A5); also elsewhere on the board
ATN: J3.32 (ATN), R16.1, U5.22 (2B7)
ATNT: U5.27 (2A7); also elsewhere on the board
BP_INTr: U5.24 (2DIR); also elsewhere on the board
BP_TATr: U5.1 (1DIR); also elsewhere on the board
BSY: J3.36 (BSY), R14.1, U5.11 (1B7)
BSYT: U5.38 (1A7); also elsewhere on the board
CD: J3.46 (C/D), R12.1, U5.6 (1B4)
CDT: U5.43 (1A4); also elsewhere on the board
DB0: J3.2 (DB0), R11.2, U4.23 (2B8)
DB0T: U4.26 (2A8); also elsewhere on the board
DB1: J3.4 (DB1), R10.2, U4.20 (2B6)
DB1T: U4.29 (2A6); also elsewhere on the board
DB2: J3.6 (DB2), R5.2, U4.19 (2B5)
DB2T: U4.30 (2A5); also elsewhere on the board
DB3: J3.8 (DB3), R7.2, U4.17 (2B4)
DB3T: U4.32 (2A4); also elsewhere on the board
DB4: J3.10 (DB4), R9.2, U4.13 (2B1)
DB4T: U4.36 (2A1); also elsewhere on the board
DB5: J3.12 (DB5), R8.2, U4.12 (1B8)
DB5T: U4.37 (1A8); also elsewhere on the board
DB6: J3.14 (DB6), R6.2, U4.8 (1B5)
DB6T: U4.41 (1A5); also elsewhere on the board
DB7: J3.16 (DB7), R4.2, U4.6 (1B4)
DB7T: U4.43 (1A4); also elsewhere on the board
DBP: J3.18 (DBP), R1.2, U4.2 (1B1)
DBPT: U4.47 (1A1); also elsewhere on the board
DBPTr: U4.1 (1DIR), U4.24 (2DIR); also elsewhere on the board
GND: C1.2, C2.2, C3.2, C4.2, C5.2, C6.2, C7.2, C8.2, C9.2, C10.2, C11.2, C12.2, J1.1, J2.3, J3.1 (GND), J3.3 (GND), J3.5 (GND), J3.7 (GND), J3.9 (GND), J3.11 (GND), J3.13 (GND), J3.15 (GND), J3.17 (GND), J3.19 (GND), J3.21 (GND), J3.23 (GND), J3.27 (GND), J3.29 (GND), J3.31 (GND), J3.33 (GND), J3.35 (GND), J3.37 (GND), J3.39 (GND), J3.41 (GND), J3.43 (GND), J3.45 (GND), J3.47 (GND), J3.49 (GND), J4.2 (GND), J4.3 (GND), SD1.5 (GND), SD1.8 (GND), SD1.12 (GND), SD1.13 (GND), SD1.14 (GND), SD1.15 (GND), U1.11 (A10), U1.12 (GND), U1.13 (B10), U2.11 (A10), U2.12 (GND), U2.13 (B10), U3.1 (GND), U4.3 (1B2), U4.4 (GND), U4.5 (1B3), U4.9 (1B6), U4.10 (GND), U4.11 (1B7), U4.14 (2B2), U4.15 (GND), U4.16 (2B3), U4.21 (GND), U4.22 (2B7), U4.25 (/2OE), U4.27 (2A7), U4.28 (GND), U4.33 (2A3), U4.34 (GND), U4.35 (2A2), U4.38 (1A7), U4.39 (GND), U4.40 (1A6), U4.44 (1A3), U4.45 (GND), U4.46 (1A2), U4.48 (/OE), U5.4 (GND), U5.5 (1B3), U5.9 (1B6), U5.10 (GND), U5.12 (1B8), U5.13 (2B1), U5.15 (GND), U5.16 (2B3), U5.20 (2B6), U5.21 (GND), U5.23 (2B8), U5.25 (/2OE), U5.26 (2A8), U5.28 (GND), U5.29 (2A6), U5.33 (2A3), U5.34 (GND), U5.36 (2A1), U5.37 (1A8), U5.39 (GND), U5.40 (1A6), U5.44 (1A3), U5.45 (GND), U5.48 (/OE); also elsewhere on the board
IO: J3.50 (IO), R3.2, U5.2 (1B1)
IOT: U5.47 (1A1); also elsewhere on the board
MSG: J3.42 (MSG), R13.1, U5.8 (1B5)
MSGT: U5.41 (1A5); also elsewhere on the board
unnamed: D2.2 (A), J4.1 (5V)
unnamed: J1.2, R21.1
unnamed: J2.2, R19.1, U1.23 (/OE), U2.23 (/OE)
unnamed: R1.1, U1.22 (B1)
unnamed: R2.1, U2.21 (B2)
unnamed: R3.1, U2.22 (B1)
unnamed: R4.1, U1.21 (B2)
unnamed: R5.1, U1.16 (B7)
unnamed: R6.1, U1.20 (B3)
unnamed: R7.1, U1.17 (B6)
unnamed: R8.1, U1.19 (B4)
unnamed: R9.1, U1.18 (B5)
unnamed: R10.1, U1.15 (B8)
unnamed: R11.1, U1.14 (B9)
unnamed: R12.2, U2.20 (B3)
unnamed: R13.2, U2.19 (B4)
unnamed: R14.2, U2.18 (B5)
unnamed: R15.2, U2.17 (B6)
unnamed: R16.2, U2.14 (B9)
unnamed: R17.2, U2.15 (B8)
unnamed: R18.2, U2.16 (B7)
unnamed 69: R21.2; also elsewhere on the board
REQ: J3.48 (REQ), R2.2, U5.3 (1B2)
REQT: U5.46 (1A2); also elsewhere on the board
RST: J3.40 (RST), R18.1, U5.17 (2B4)
RSTT: U5.32 (2A4); also elsewhere on the board
SD_CLK: SD1.6 (CLK); also elsewhere on the board
SD_CS: SD1.10 (CD/CS/DAT3); also elsewhere on the board
SD_MISO: SD1.4 (DAT0/MISO); also elsewhere on the board
SD_MOSI: SD1.9 (CMD/MOSI); also elsewhere on the board
SEL: J3.44 (SEL), R15.1, U5.14 (2B2)
SELT: U5.35 (2A2); also elsewhere on the board

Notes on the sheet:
© 2021 - 2022 Tech by Androda, LLC licensed Attribution-NonCommercial-ShareAlike 4.0 International (CC BY-NC-SA 4.0) https://creativecommons.org/licenses/by-nc-sa/4.0/legalcode
F4Lite XCVR, SMD V1

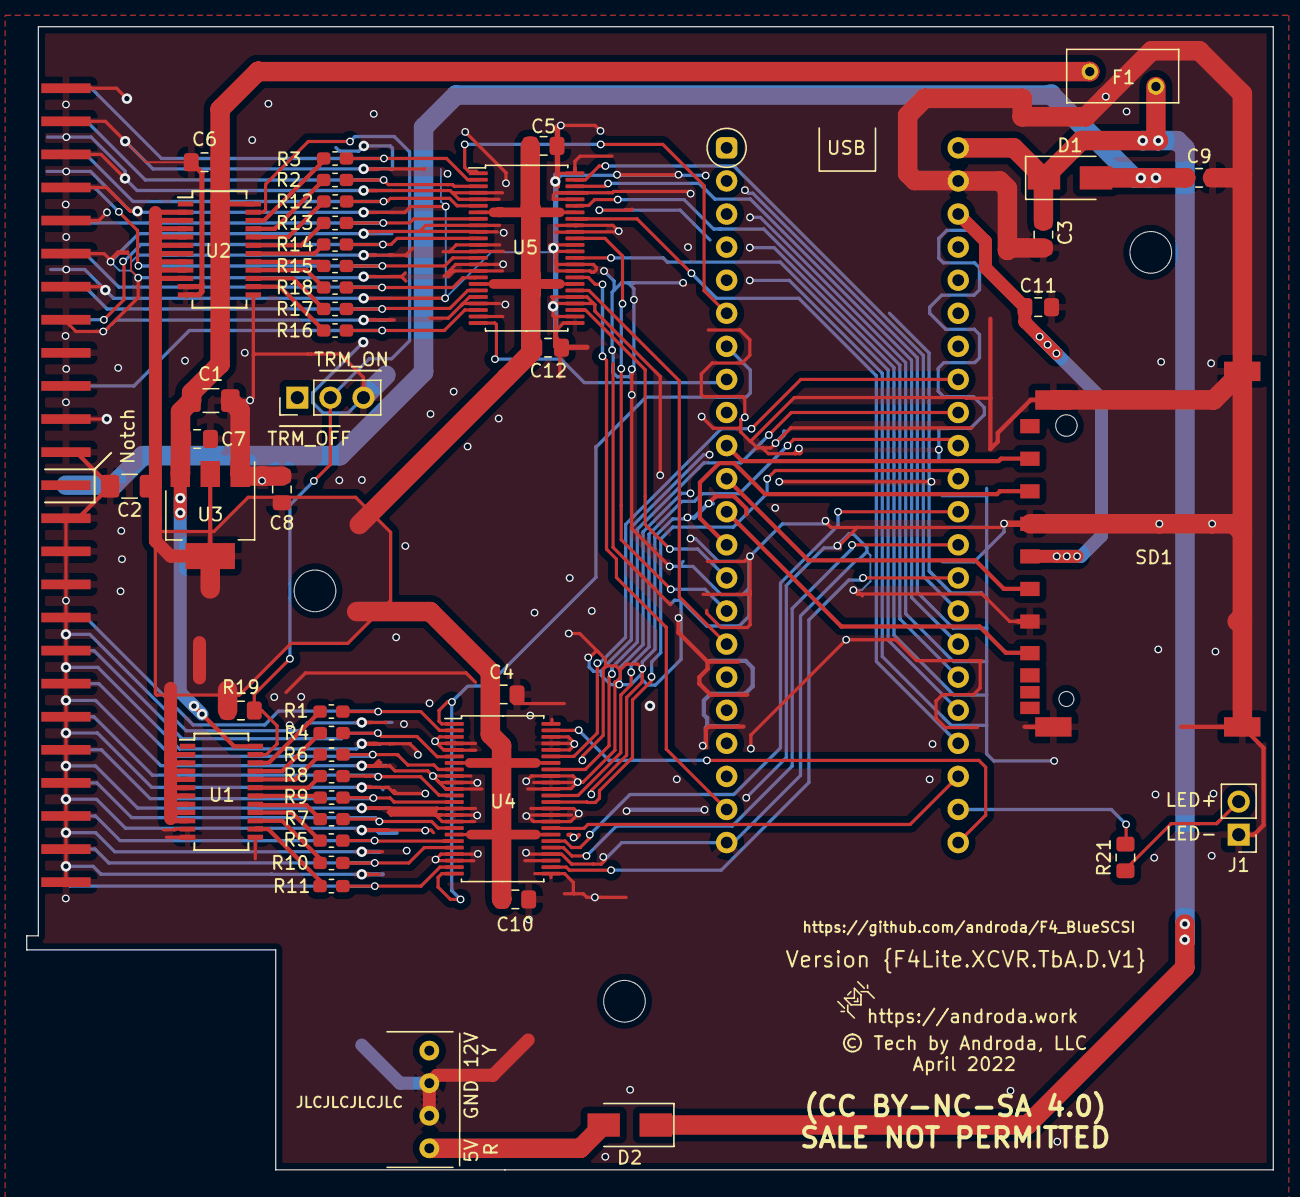
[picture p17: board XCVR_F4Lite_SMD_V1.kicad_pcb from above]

Board: 2 copper layers, 95.7 x 87.8 mm, 46 parts (0 on the bottom side), 71 nets.

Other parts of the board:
U6: GreenSCSI_F401

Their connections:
+3V3: U6.42; also elsewhere on the board
+5VP: U6.44; also elsewhere on the board
ACKT: U6.16; also elsewhere on the board
ATNT: U6.14; also elsewhere on the board
BP_INTr: U6.8; also elsewhere on the board
BP_TATr: U6.6; also elsewhere on the board
BSYT: U6.15; also elsewhere on the board
CDT: U6.28; also elsewhere on the board
DB0T: U6.31; also elsewhere on the board
DB1T: U6.32; also elsewhere on the board
DB2T: U6.33; also elsewhere on the board
DB3T: U6.25; also elsewhere on the board
DB4T: U6.34; also elsewhere on the board
DB5T: U6.35; also elsewhere on the board
DB6T: U6.36; also elsewhere on the board
DB7T: U6.37; also elsewhere on the board
DBPT: U6.23; also elsewhere on the board
DBPTr: U6.7; also elsewhere on the board
GND: U6.22, U6.43; also elsewhere on the board
IOT: U6.30; also elsewhere on the board
MSGT: U6.26; also elsewhere on the board
unnamed 69: U6.24; also elsewhere on the board
REQT: U6.29; also elsewhere on the board
RSTT: U6.21; also elsewhere on the board
SD_CLK: U6.11; also elsewhere on the board
SD_CS: U6.10; also elsewhere on the board
SD_MISO: U6.12; also elsewhere on the board
SD_MOSI: U6.13; also elsewhere on the board
SELT: U6.27; also elsewhere on the board

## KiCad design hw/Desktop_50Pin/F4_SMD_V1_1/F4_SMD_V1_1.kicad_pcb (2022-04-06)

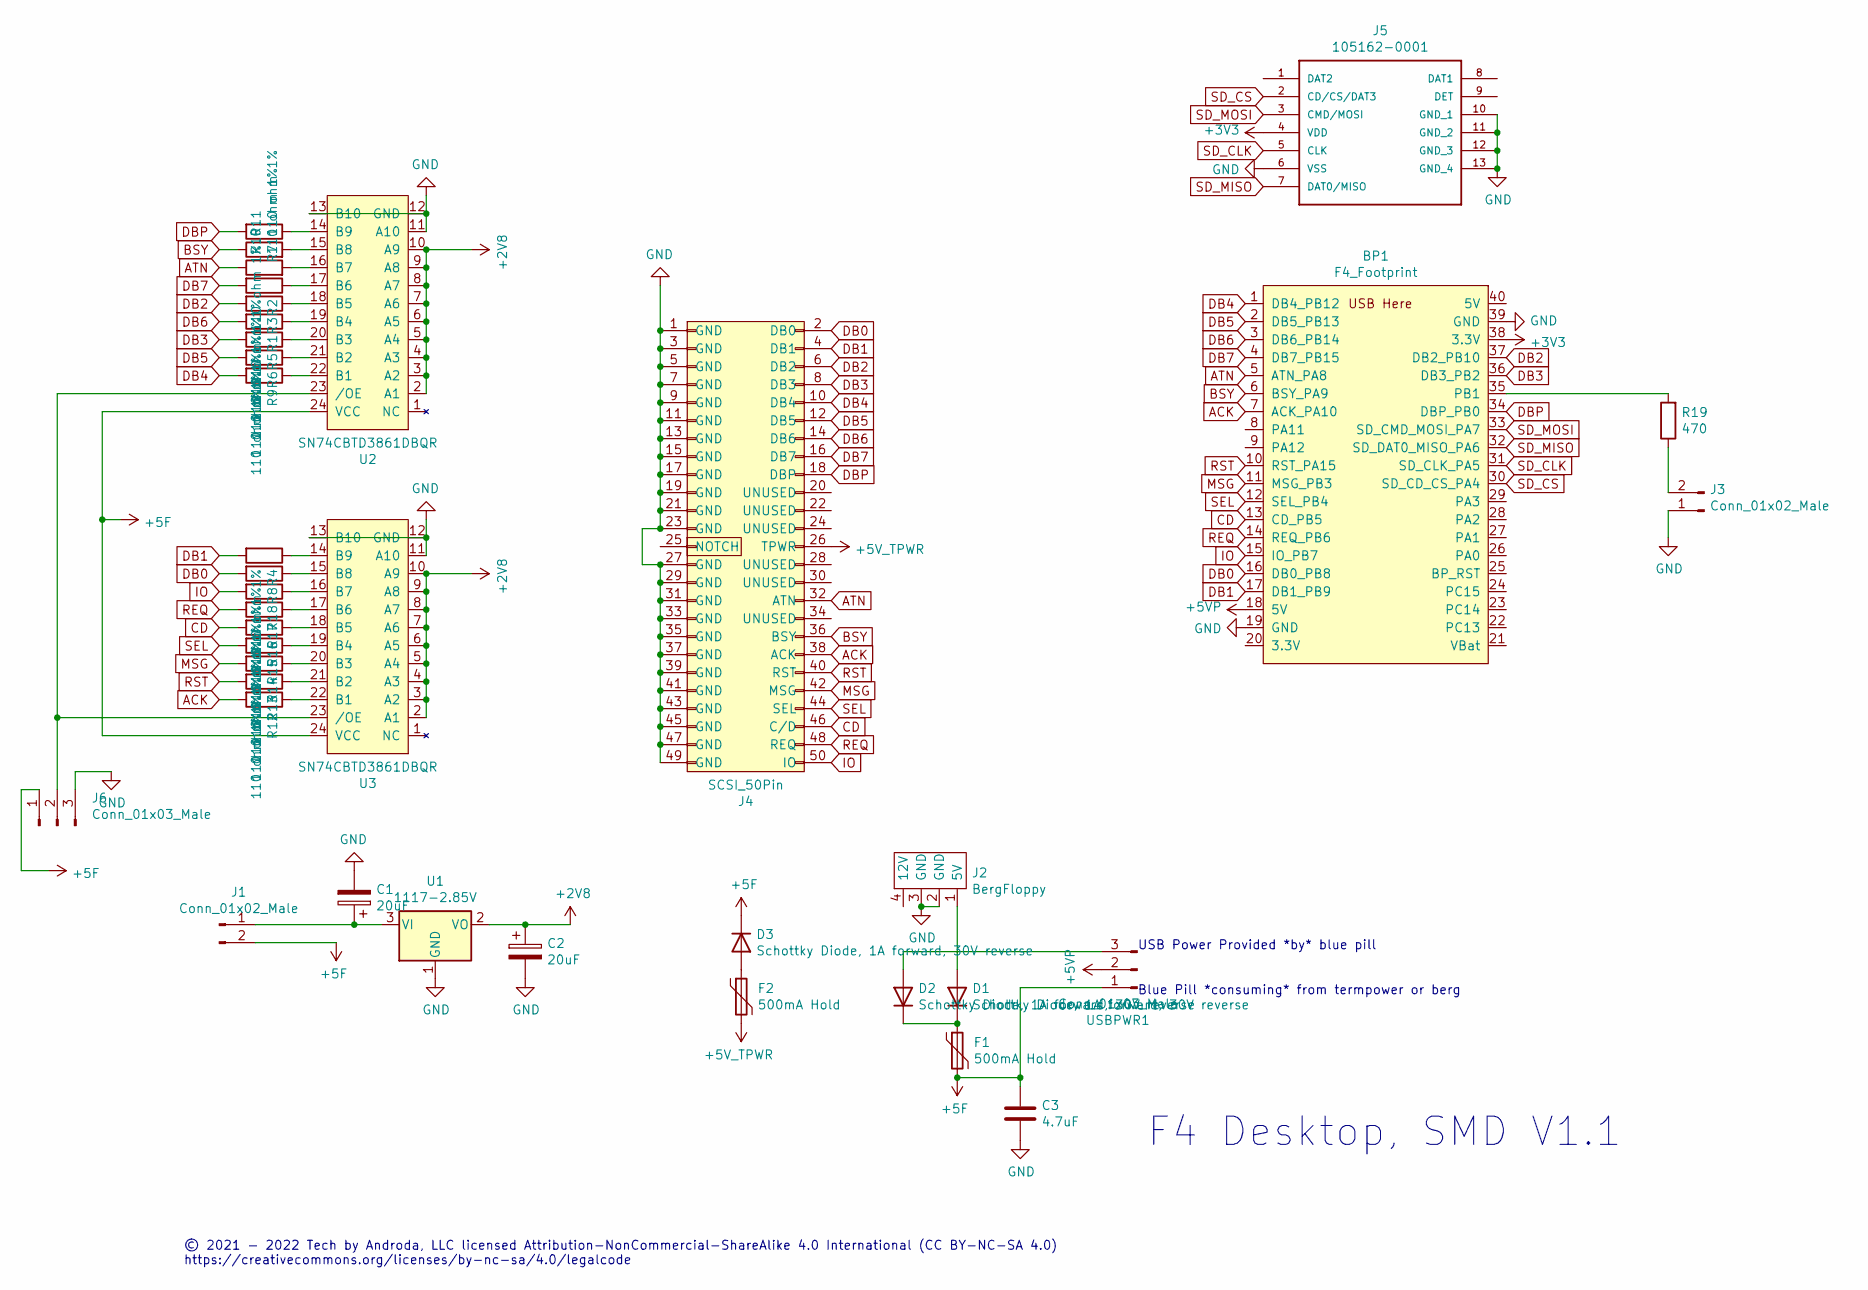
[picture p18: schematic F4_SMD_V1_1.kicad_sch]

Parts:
BP1: F4_Footprint; BluePillModule
C1, C2: 20uF; C_1206_3216Metric_Pad1.42x1.75mm_HandSolder
C3: 4.7uF; C_0805_2012Metric_Pad1.15x1.40mm_HandSolder
D1, D2, D3: Schottky Diode, 1A forward, 30V reverse; D_SOD-123F
F1, F2: 500mA Hold; Fuse_0805_2012Metric_Castellated
J1, J3: Conn_01x02_Male; PinHeader_1x02_P2.54mm_Vertical
J2: BergFloppy; BergFloppy_RightAngle
J4: SCSI_50Pin; SCSI_Internal_50Pin
J5: 105162-0001; microsd_molex_1051620001; MANUFACTURER_PART_NUMBER 105162-0001; MOUSER_PART_NUMBER 538-105162-0001
J6: Conn_01x03_Male; PinHeader_1x03_P2.54mm_Vertical
R1, R2, R3, R4, R5, R6, R7, R8, R9, R10, R11, R12, R13, R14, R15, R16, R17, R18: 110 ohm 1%; R_0603_1608Metric_Pad1.05x0.95mm_HandSolder
R19: 470; R_Axial_DIN0207_L6.3mm_D2.5mm_P7.62mm_Horizontal
U1: 1117-2.85V; SOT-223-3_TabPin2
U2, U3: SN74CBTD3861DBQR; SSOP-24_3.9x8.7mm_P0.635mm
USBPWR1: Conn_01x03_Male; PinHeader_1x03_P2.54mm_Vertical

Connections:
+2V8: C2.1, U1.2 (VO), U2.2 (A1), U2.3 (A2), U2.4 (A3), U2.5 (A4), U2.6 (A5), U2.7 (A6), U2.8 (A7), U2.9 (A8), U2.10 (A9), U3.2 (A1), U3.3 (A2), U3.4 (A3), U3.5 (A4), U3.6 (A5), U3.7 (A6), U3.8 (A7), U3.9 (A8), U3.10 (A9)
+3V3: BP1.38 (3.3V), J5.4 (VDD)
+5F: C3.1, D3.1 (K), F1.2, J1.2, J6.1, U2.24 (VCC), U3.24 (VCC), USBPWR1.1; also elsewhere on the board
+5V: F2.2, J4.26 (TPWR)
+5VP: BP1.18 (5V), USBPWR1.2; also elsewhere on the board
ACK: BP1.7 (ACK_PA10), J4.38 (ACK), R12.2
ATN: BP1.5 (ATN_PA8), J4.32 (ATN), R10.1
BSY: BP1.6 (BSY_PA9), J4.36 (BSY), R11.1
CD: BP1.13 (CD_PB5), J4.46 (C/D), R16.2
DB0: BP1.16 (DB0_PB8), J4.2 (DB0), R8.2
DB1: BP1.17 (DB1_PB9), J4.4 (DB1), R4.2
DB2: BP1.37 (DB2_PB10), J4.6 (DB2), R3.2
DB3: BP1.36 (DB3_PB2), J4.8 (DB3), R5.2
DB4: BP1.1 (DB4_PB12), J4.10 (DB4), R9.2
DB5: BP1.2 (DB5_PB13), J4.12 (DB5), R6.2
DB6: BP1.3 (DB6_PB14), J4.14 (DB6), R1.2
DB7: BP1.4 (DB7_PB15), J4.16 (DB7), R2.2
DBP: BP1.34 (DBP_PB0), J4.18 (DBP), R7.2
GND: BP1.19 (GND), BP1.39 (GND), C1.2, C2.2, C3.2, J2.2 (GND), J2.3 (GND), J3.1, J4.1 (GND), J4.3 (GND), J4.5 (GND), J4.7 (GND), J4.9 (GND), J4.11 (GND), J4.13 (GND), J4.15 (GND), J4.17 (GND), J4.19 (GND), J4.21 (GND), J4.23 (GND), J4.27 (GND), J4.29 (GND), J4.31 (GND), J4.33 (GND), J4.35 (GND), J4.37 (GND), J4.39 (GND), J4.41 (GND), J4.43 (GND), J4.45 (GND), J4.47 (GND), J4.49 (GND), J5.6 (VSS), J5.10 (GND_1), J5.11 (GND_2), J5.12 (GND_3), J5.13 (GND_4), J6.3, U1.1 (GND), U2.11 (A10), U2.12 (GND), U2.13 (B10), U3.11 (A10), U3.12 (GND), U3.13 (B10)
IO: BP1.15 (IO_PB7), J4.50 (IO), R18.2
MSG: BP1.11 (MSG_PB3), J4.42 (MSG), R14.2
unnamed: BP1.35 (PB1), R19.2
unnamed: C1.1, J1.1, U1.3 (VI)
unnamed: D1.1 (K), D2.1 (K), F1.1
unnamed: D1.2 (A), J2.1 (5V)
unnamed 25: D2.2 (A), USBPWR1.3; also elsewhere on the board
unnamed: D3.2 (A), F2.1
unnamed: J3.2, R19.1
unnamed: J6.2, U2.23 (/OE), U3.23 (/OE)
unnamed: R1.1, U2.19 (B4)
unnamed: R2.1, U2.17 (B6)
unnamed: R3.1, U2.18 (B5)
unnamed: R4.1, U3.14 (B9)
unnamed: R5.1, U2.20 (B3)
unnamed: R6.1, U2.21 (B2)
unnamed: R7.1, U2.14 (B9)
unnamed: R8.1, U3.15 (B8)
unnamed: R9.1, U2.22 (B1)
unnamed: R10.2, U2.16 (B7)
unnamed: R11.2, U2.15 (B8)
unnamed: R12.1, U3.22 (B1)
unnamed: R13.1, U3.21 (B2)
unnamed: R14.1, U3.20 (B3)
unnamed: R15.1, U3.19 (B4)
unnamed: R16.1, U3.18 (B5)
unnamed: R17.1, U3.17 (B6)
unnamed: R18.1, U3.16 (B7)
REQ: BP1.14 (REQ_PB6), J4.48 (REQ), R17.2
RST: BP1.10 (RST_PA15), J4.40 (RST), R13.2
SD_CLK: BP1.31 (SD_CLK_PA5), J5.5 (CLK)
SD_CS: BP1.30 (SD_CD_CS_PA4), J5.2 (CD/CS/DAT3)
SD_MISO: BP1.32 (SD_DAT0_MISO_PA6), J5.7 (DAT0/MISO)
SD_MOSI: BP1.33 (SD_CMD_MOSI_PA7), J5.3 (CMD/MOSI)
SEL: BP1.12 (SEL_PB4), J4.44 (SEL), R15.2

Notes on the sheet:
© 2021 - 2022 Tech by Androda, LLC licensed Attribution-NonCommercial-ShareAlike 4.0 International (CC BY-NC-SA 4.0) https://creativecommons.org/licenses/by-nc-sa/4.0/legalcode
F4 Desktop, SMD V1.1
Blue Pill *consuming* from termpower or berg
USB Power Provided *by* blue pill

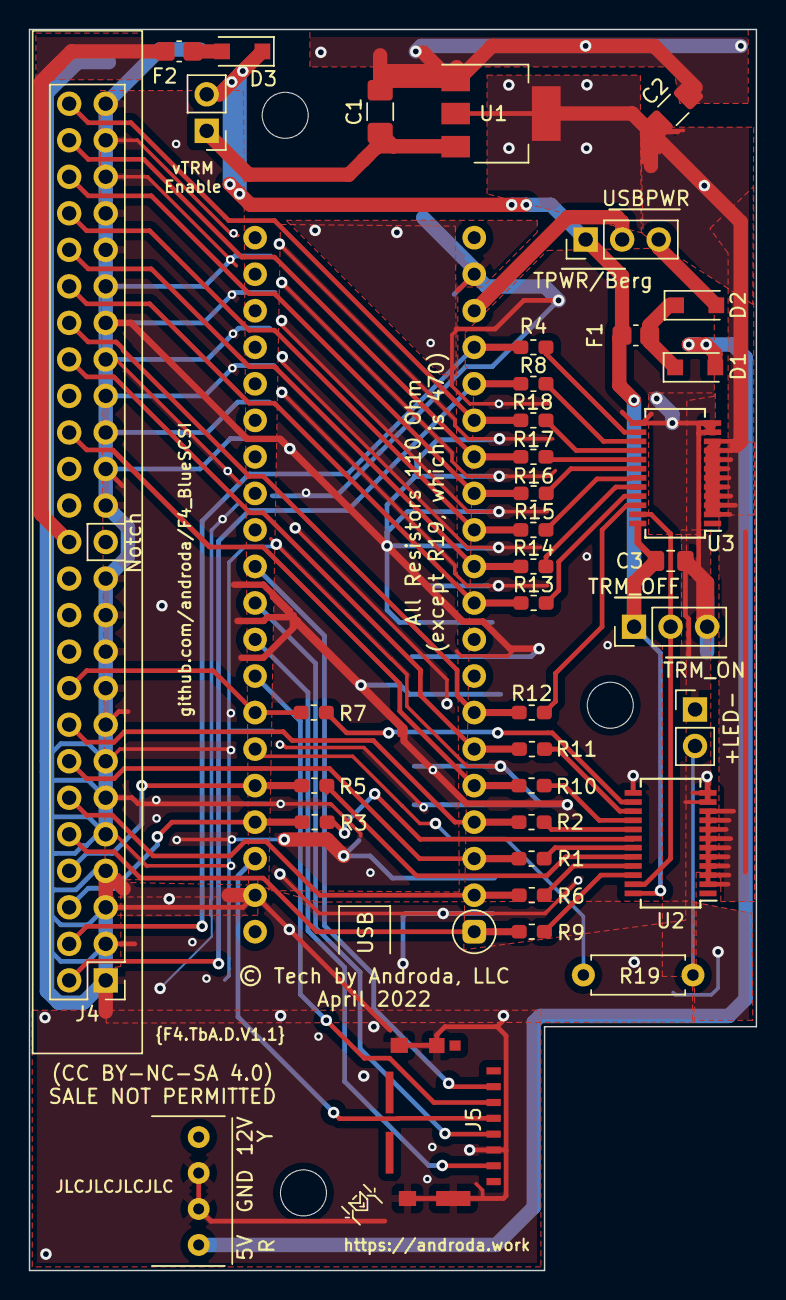
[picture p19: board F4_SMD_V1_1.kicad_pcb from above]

Board: 2 copper layers, 50.5 x 86.3 mm, 38 parts (0 on the bottom side), 54 nets.

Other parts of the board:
USBPWR: Conn_01x03_Male; PinHeader_1x03_P2.54mm_Vertical

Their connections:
+5F: USBPWR.1; also elsewhere on the board
+5VP: USBPWR.2; also elsewhere on the board
unnamed 25: USBPWR.3; also elsewhere on the board

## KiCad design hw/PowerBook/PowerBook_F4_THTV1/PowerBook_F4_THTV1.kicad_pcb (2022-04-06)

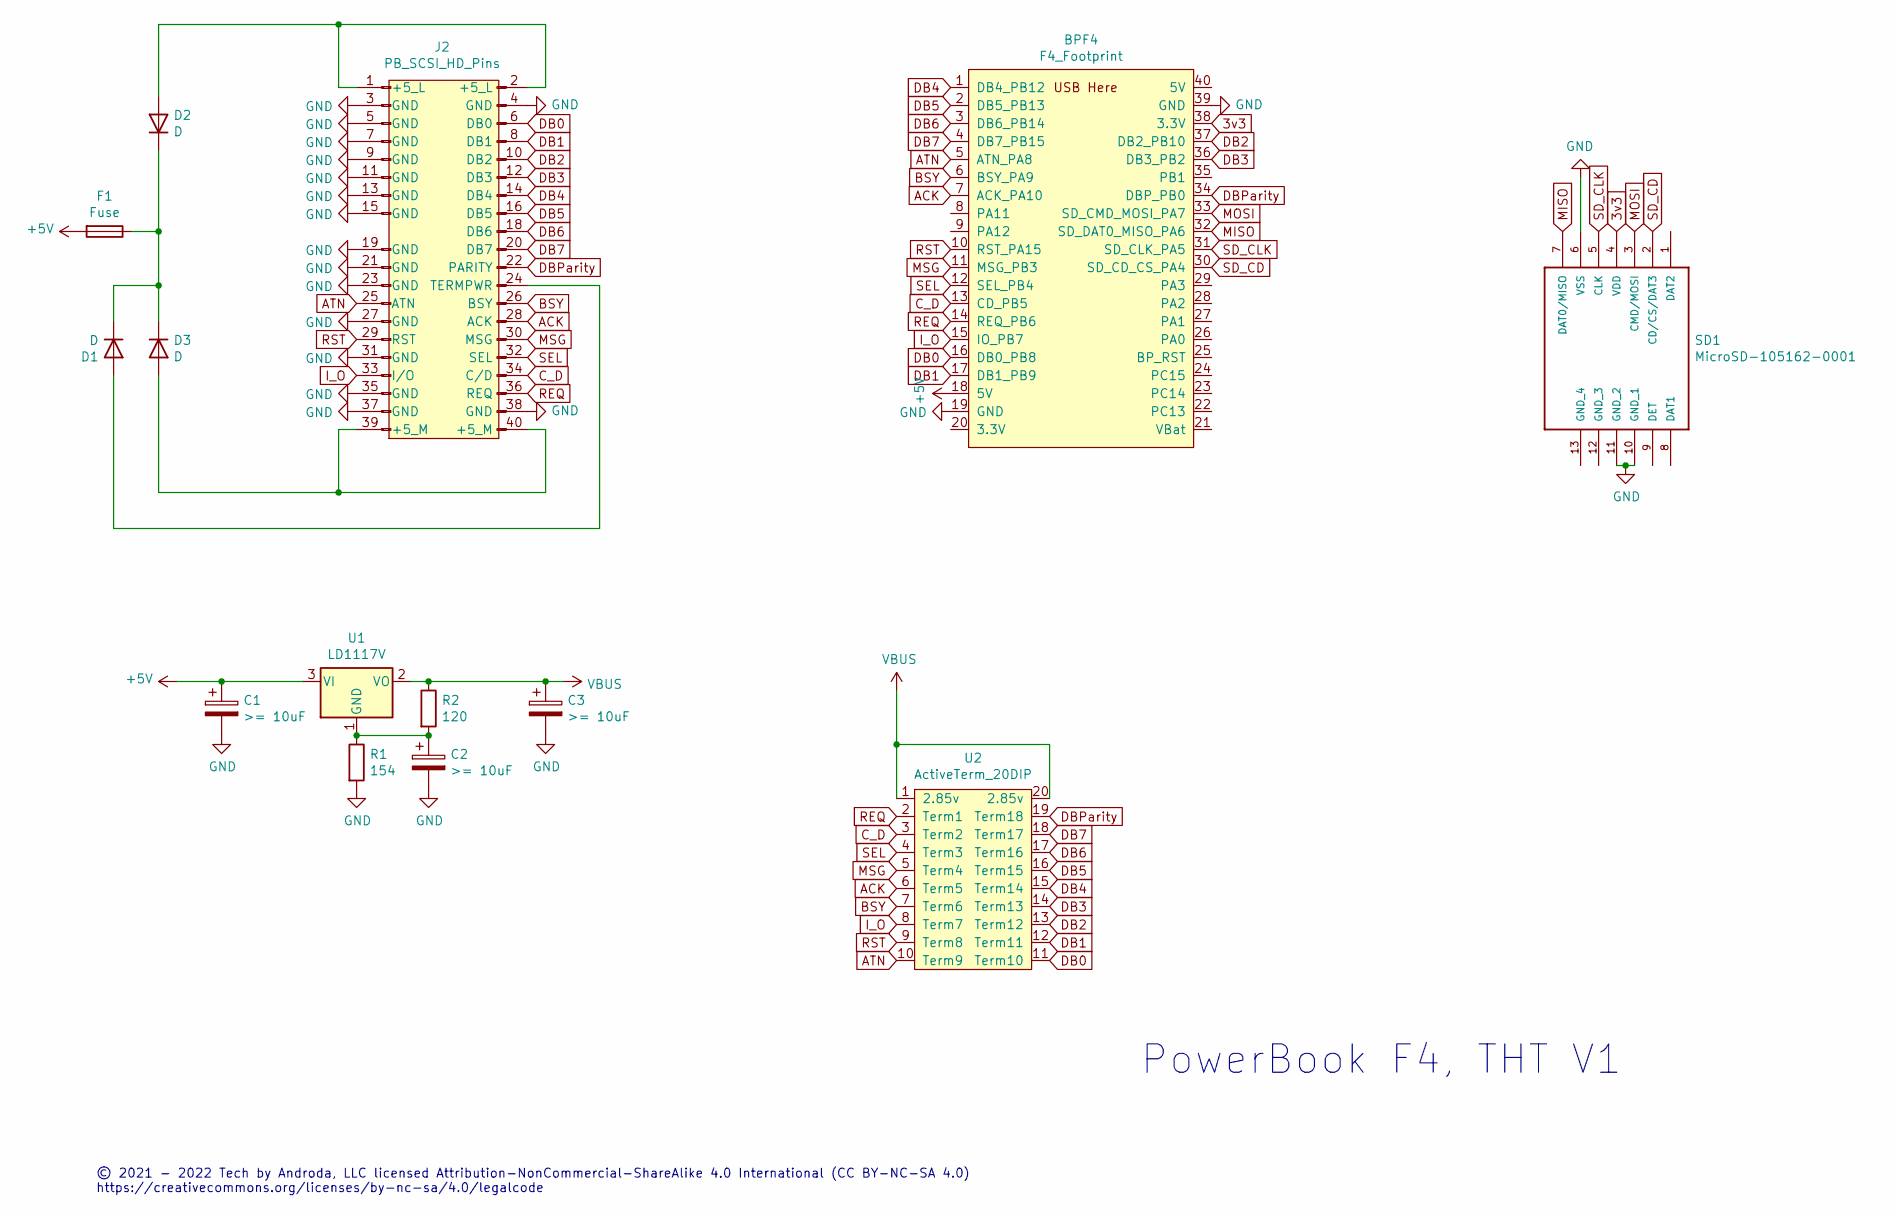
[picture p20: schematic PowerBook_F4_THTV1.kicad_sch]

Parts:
BPF4: F4_Footprint; BluePillModule
C1, C2, C3: >= 10uF; C_1206_3216Metric_Pad1.42x1.75mm_HandSolder
D1, D2, D3: D; D_A-405_P10.16mm_Horizontal
F1: Fuse; Fuse_BelFuse_0ZRE0005FF_L8.3mm_W3.8mm
J2: PB_SCSI_HD_Pins; PowerBook_SCSI_40Pin_UpsideDown
R1: 154; R_Axial_DIN0204_L3.6mm_D1.6mm_P7.62mm_Horizontal
R2: 120; R_Axial_DIN0204_L3.6mm_D1.6mm_P5.08mm_Vertical
SD1: MicroSD-105162-0001; microsd_molex_1051620001; MANUFACTURER_PART_NUMBER 105162-0001; MOUSER_PART_NUMBER 538-105162-0001
U1: LD1117V; TO-220-3_Horizontal_TabDown
U2: ActiveTerm_20DIP; DIP-20_W7.62mm_Socket

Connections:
3v3: BPF4.38 (3.3V), SD1.4 (VDD)
+5V: BPF4.18 (5V), C1.1, F1.2, U1.3 (VI)
ACK: BPF4.7 (ACK_PA10), J2.28 (ACK), U2.6 (Term5)
ATN: BPF4.5 (ATN_PA8), J2.25 (ATN), U2.10 (Term9)
BSY: BPF4.6 (BSY_PA9), J2.26 (BSY), U2.7 (Term6)
C_D: BPF4.13 (CD_PB5), J2.34 (C/D), U2.3 (Term2)
DB0: BPF4.16 (DB0_PB8), J2.6 (DB0), U2.11 (Term10)
DB1: BPF4.17 (DB1_PB9), J2.8 (DB1), U2.12 (Term11)
DB2: BPF4.37 (DB2_PB10), J2.10 (DB2), U2.13 (Term12)
DB3: BPF4.36 (DB3_PB2), J2.12 (DB3), U2.14 (Term13)
DB4: BPF4.1 (DB4_PB12), J2.14 (DB4), U2.15 (Term14)
DB5: BPF4.2 (DB5_PB13), J2.16 (DB5), U2.16 (Term15)
DB6: BPF4.3 (DB6_PB14), J2.18 (DB6), U2.17 (Term16)
DB7: BPF4.4 (DB7_PB15), J2.20 (DB7), U2.18 (Term17)
DBParity: BPF4.34 (DBP_PB0), J2.22 (PARITY), U2.19 (Term18)
GND: BPF4.19 (GND), BPF4.39 (GND), C1.2, C2.2, C3.2, J2.3 (GND), J2.4 (GND), J2.5 (GND), J2.7 (GND), J2.9 (GND), J2.11 (GND), J2.13 (GND), J2.15 (GND), J2.19 (GND), J2.21 (GND), J2.23 (GND), J2.27 (GND), J2.31 (GND), J2.35 (GND), J2.37 (GND), J2.38 (GND), R1.2, SD1.6 (VSS), SD1.10 (GND_1), SD1.11 (GND_2)
I_O: BPF4.15 (IO_PB7), J2.33 (I/O), U2.8 (Term7)
MISO: BPF4.32 (SD_DAT0_MISO_PA6), SD1.7 (DAT0/MISO)
MOSI: BPF4.33 (SD_CMD_MOSI_PA7), SD1.3 (CMD/MOSI)
MSG: BPF4.11 (MSG_PB3), J2.30 (MSG), U2.5 (Term4)
unnamed: C2.1, R1.1, R2.2, U1.1 (GND)
unnamed: D1.1 (K), D2.1 (K), D3.1 (K), F1.1
unnamed: D1.2 (A), J2.24 (TERMPWR)
unnamed: D2.2 (A), J2.1 (+5_L), J2.2 (+5_L)
unnamed: D3.2 (A), J2.39 (+5_M), J2.40 (+5_M)
REQ: BPF4.14 (REQ_PB6), J2.36 (REQ), U2.2 (Term1)
RST: BPF4.10 (RST_PA15), J2.29 (RST), U2.9 (Term8)
SD_CD: BPF4.30 (SD_CD_CS_PA4), SD1.2 (CD/CS/DAT3)
SD_CLK: BPF4.31 (SD_CLK_PA5), SD1.5 (CLK)
SEL: BPF4.12 (SEL_PB4), J2.32 (SEL), U2.4 (Term3)
VBUS: C3.1, R2.1, U1.2 (VO), U2.1 (2.85v), U2.20 (2.85v)

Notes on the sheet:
PowerBook F4, THT V1
© 2021 - 2022 Tech by Androda, LLC licensed Attribution-NonCommercial-ShareAlike 4.0 International (CC BY-NC-SA 4.0) https://creativecommons.org/licenses/by-nc-sa/4.0/legalcode

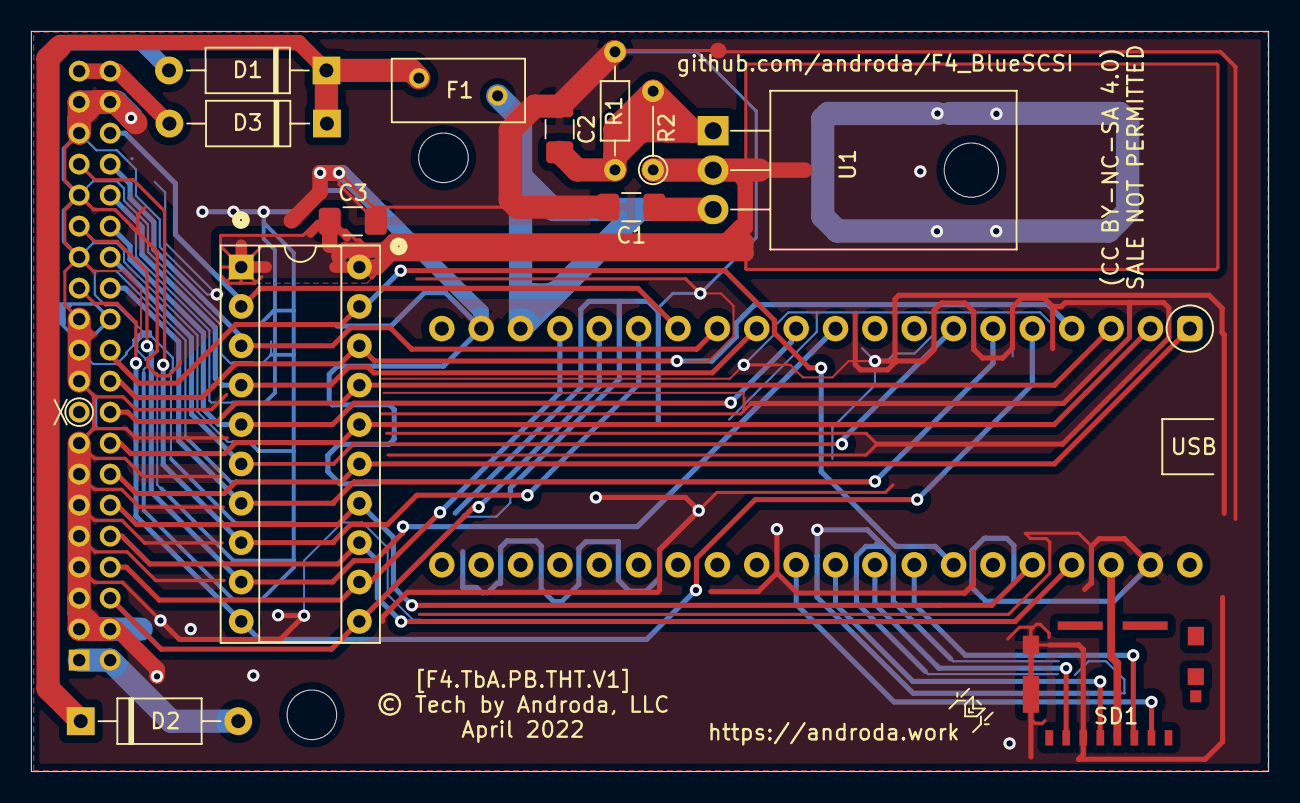
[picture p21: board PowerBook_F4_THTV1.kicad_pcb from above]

Board: 2 copper layers, 79.8 x 47.8 mm, 14 parts (0 on the bottom side), 31 nets.

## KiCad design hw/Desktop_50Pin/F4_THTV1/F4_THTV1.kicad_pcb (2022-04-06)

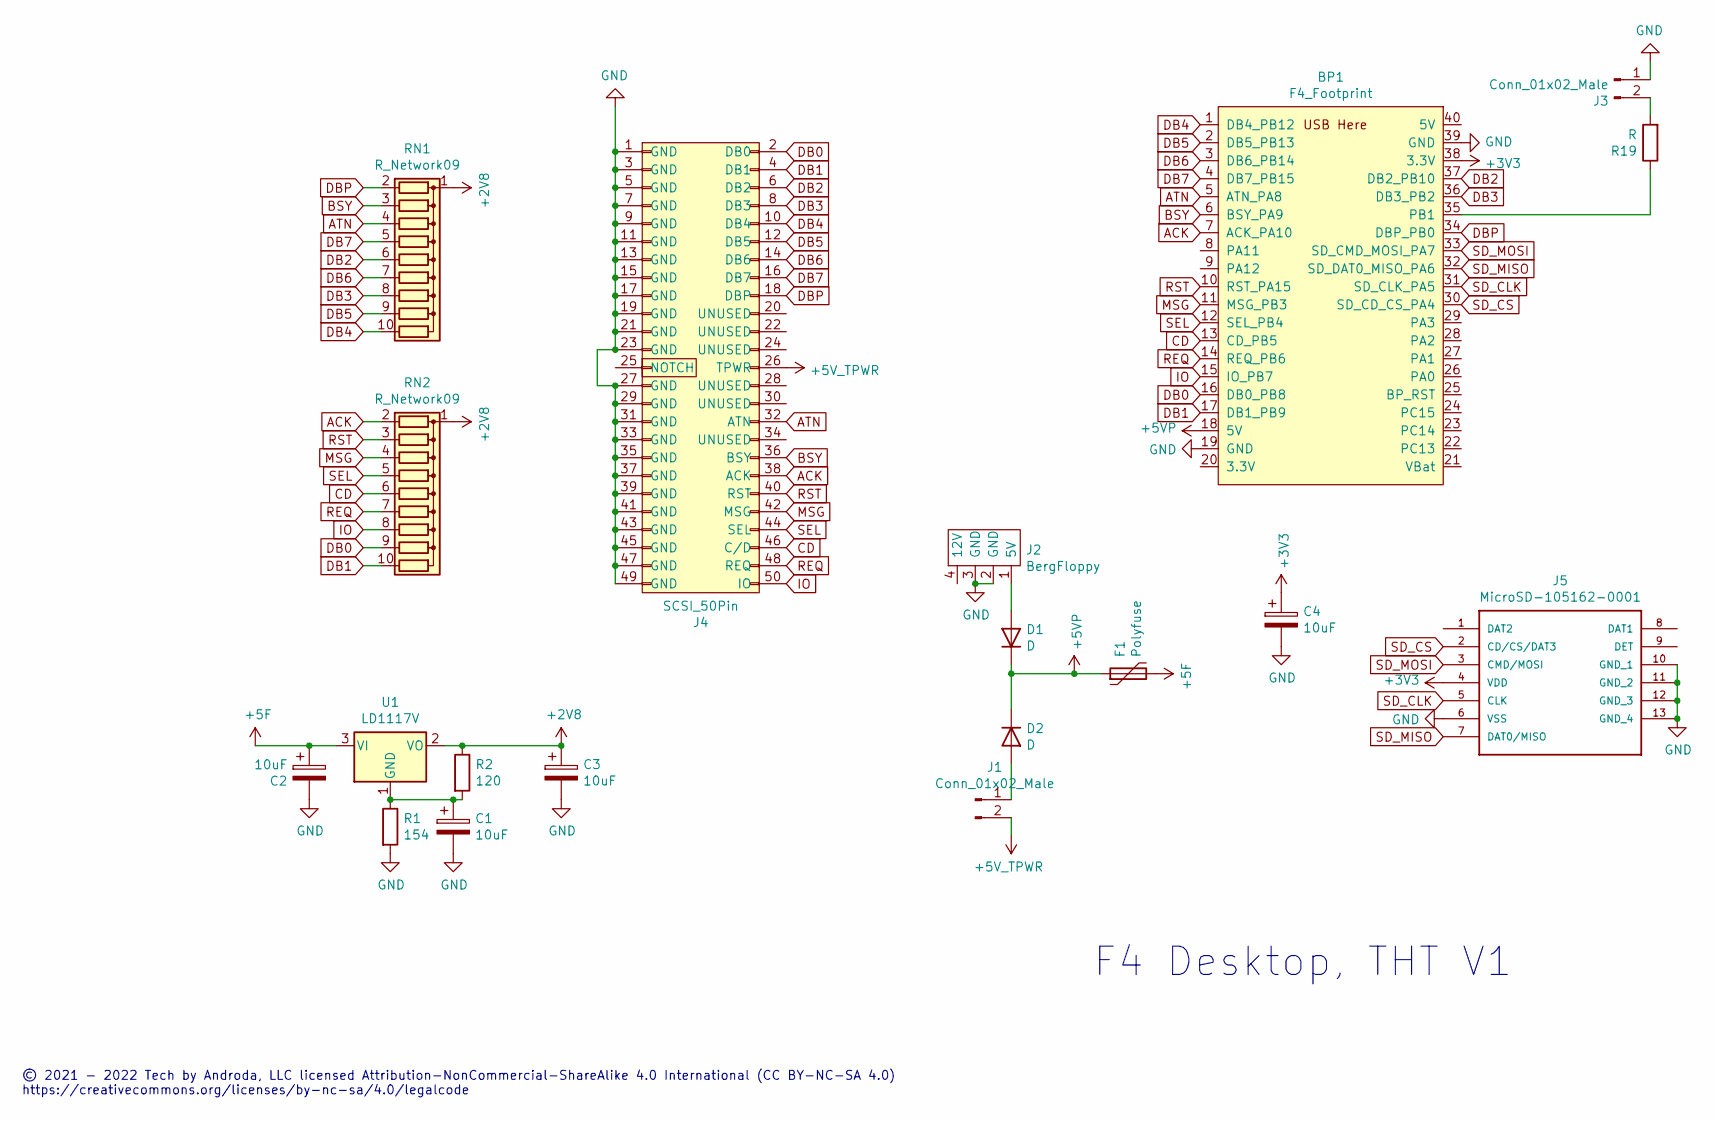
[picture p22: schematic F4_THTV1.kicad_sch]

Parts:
BP1: F4_Footprint; BluePillModule
C1, C2, C3, C4: 10uF; C_1210_3225Metric_Pad1.42x2.65mm_HandSolder
D1, D2: D; D_A-405_P7.62mm_Horizontal
F1: Polyfuse; Fuse_BelFuse_0ZRE0005FF_L8.3mm_W3.8mm
J1, J3: Conn_01x02_Male; PinHeader_1x02_P2.54mm_Vertical
J2: BergFloppy; BergFloppy_RightAngle
J4: SCSI_50Pin; SCSI_Internal_50Pin
J5: MicroSD-105162-0001; microsd_molex_1051620001; MANUFACTURER_PART_NUMBER 105162-0001; MOUSER_PART_NUMBER 538-105162-0001
R1: 154; R_Axial_DIN0207_L6.3mm_D2.5mm_P10.16mm_Horizontal
R2: 120; R_Axial_DIN0204_L3.6mm_D1.6mm_P5.08mm_Vertical
R19: R; R_Axial_DIN0207_L6.3mm_D2.5mm_P7.62mm_Horizontal
RN1, RN2: R_Network09; R_Array_SIP10
U1: LD1117V; TO-220-3_Horizontal_TabDown

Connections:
+2V8: C3.1, R2.1, RN1.1 (common), RN2.1 (common), U1.2 (VO)
+3V3: BP1.38 (3.3V), C4.1, J5.4 (VDD)
+5F: C2.1, F1.2, U1.3 (VI)
+5V: J1.2, J4.26 (TPWR)
+5VP: BP1.18 (5V), D1.1 (K), D2.1 (K), F1.1
ACK: BP1.7 (ACK_PA10), J4.38 (ACK), RN2.2 (R1)
ATN: BP1.5 (ATN_PA8), J4.32 (ATN), RN1.4 (R3)
BSY: BP1.6 (BSY_PA9), J4.36 (BSY), RN1.3 (R2)
CD: BP1.13 (CD_PB5), J4.46 (C/D), RN2.6 (R5)
DB0: BP1.16 (DB0_PB8), J4.2 (DB0), RN2.9 (R8)
DB1: BP1.17 (DB1_PB9), J4.4 (DB1), RN2.10 (R9)
DB2: BP1.37 (DB2_PB10), J4.6 (DB2), RN1.6 (R5)
DB3: BP1.36 (DB3_PB2), J4.8 (DB3), RN1.8 (R7)
DB4: BP1.1 (DB4_PB12), J4.10 (DB4), RN1.10 (R9)
DB5: BP1.2 (DB5_PB13), J4.12 (DB5), RN1.9 (R8)
DB6: BP1.3 (DB6_PB14), J4.14 (DB6), RN1.7 (R6)
DB7: BP1.4 (DB7_PB15), J4.16 (DB7), RN1.5 (R4)
DBP: BP1.34 (DBP_PB0), J4.18 (DBP), RN1.2 (R1)
GND: BP1.19 (GND), BP1.39 (GND), C1.2, C2.2, C3.2, C4.2, J2.2 (GND), J2.3 (GND), J3.1, J4.1 (GND), J4.3 (GND), J4.5 (GND), J4.7 (GND), J4.9 (GND), J4.11 (GND), J4.13 (GND), J4.15 (GND), J4.17 (GND), J4.19 (GND), J4.21 (GND), J4.23 (GND), J4.27 (GND), J4.29 (GND), J4.31 (GND), J4.33 (GND), J4.35 (GND), J4.37 (GND), J4.39 (GND), J4.41 (GND), J4.43 (GND), J4.45 (GND), J4.47 (GND), J4.49 (GND), J5.6 (VSS), J5.10 (GND_1), J5.11 (GND_2), J5.12 (GND_3), J5.13 (GND_4), R1.2
IO: BP1.15 (IO_PB7), J4.50 (IO), RN2.8 (R7)
MSG: BP1.11 (MSG_PB3), J4.42 (MSG), RN2.4 (R3)
unnamed: BP1.35 (PB1), R19.1
unnamed: C1.1, R1.1, R2.2, U1.1 (GND)
unnamed: D1.2 (A), J2.1 (5V)
unnamed: D2.2 (A), J1.1
unnamed: J3.2, R19.2
REQ: BP1.14 (REQ_PB6), J4.48 (REQ), RN2.7 (R6)
RST: BP1.10 (RST_PA15), J4.40 (RST), RN2.3 (R2)
SD_CLK: BP1.31 (SD_CLK_PA5), J5.5 (CLK)
SD_CS: BP1.30 (SD_CD_CS_PA4), J5.2 (CD/CS/DAT3)
SD_MISO: BP1.32 (SD_DAT0_MISO_PA6), J5.7 (DAT0/MISO)
SD_MOSI: BP1.33 (SD_CMD_MOSI_PA7), J5.3 (CMD/MOSI)
SEL: BP1.12 (SEL_PB4), J4.44 (SEL), RN2.5 (R4)

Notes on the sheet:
F4 Desktop, THT V1
© 2021 - 2022 Tech by Androda, LLC licensed Attribution-NonCommercial-ShareAlike 4.0 International (CC BY-NC-SA 4.0) https://creativecommons.org/licenses/by-nc-sa/4.0/legalcode

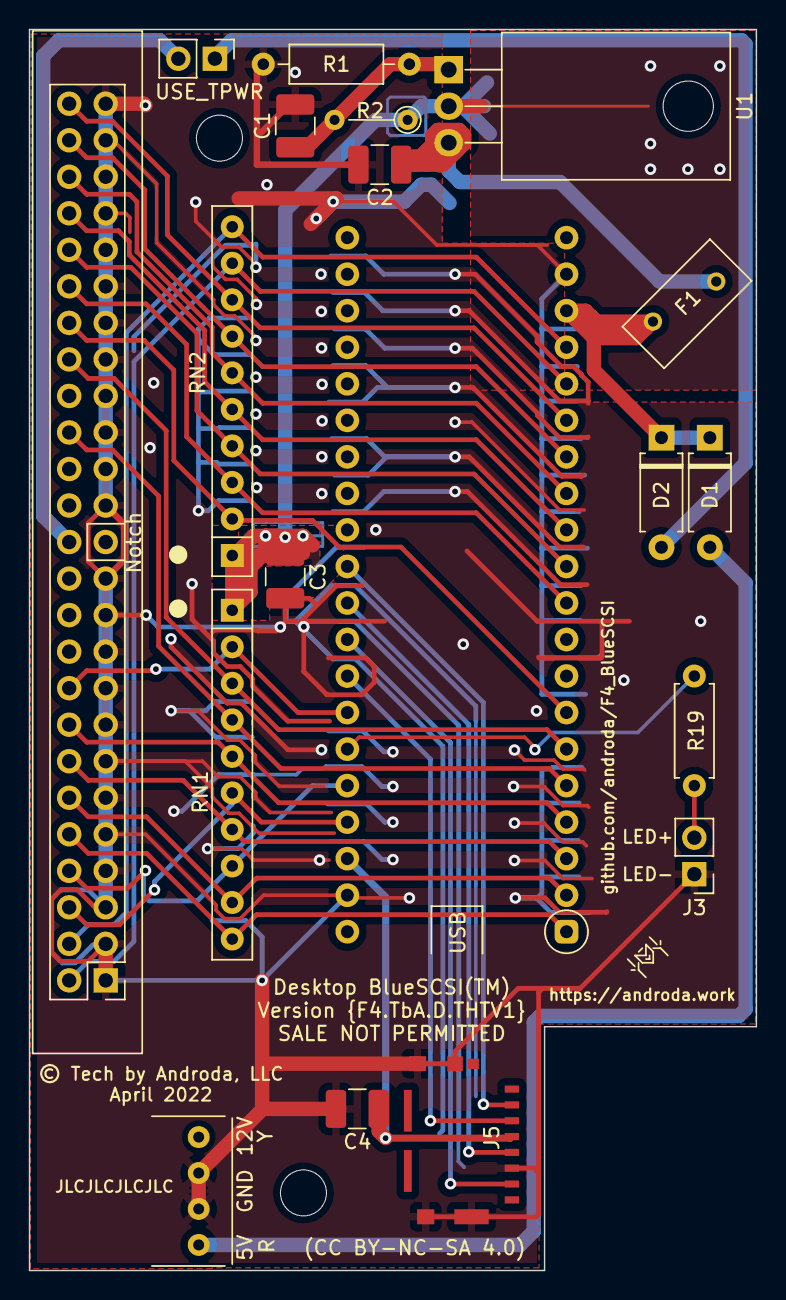
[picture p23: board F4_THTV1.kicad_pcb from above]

Board: 2 copper layers, 50.5 x 86.3 mm, 19 parts (0 on the bottom side), 33 nets.

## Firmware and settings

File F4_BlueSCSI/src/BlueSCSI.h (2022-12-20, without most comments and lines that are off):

#define __BLUESCSI_H__
#include <Arduino.h> // For Platform.IO
#include <SdFat.h>
#define MAX_SCSIID  7          // Maximum number of supported SCSI-IDs (The minimum is 0)
#define MAX_SCSILUN 8          // Maximum number of LUNs supported     (The minimum is 0)
#define NUM_SCSIID  MAX_SCSIID // Number of enabled SCSI IDs
#define NUM_SCSILUN 1          // Number of enabled LUNs
#define READ_PARITY_CHECK 0    // Perform read parity check (unverified)
#define DEFAULT_SCSI_ID 1
#define DEFAULT_SCSI_LUN 0
#define SCSI_BUF_SIZE 512      // Size of the SCSI Buffer
#define HDD_BLOCK_SIZE 512
#define OPTICAL_BLOCK_SIZE 2048
#define MAX_BLOCKSIZE 4096     // Maximum BLOCK size
#define ERROR_FALSE_INIT  3
#define ERROR_NO_SDCARD   5
enum SCSI_DEVICE_TYPE
{
  SCSI_DEVICE_HDD,
  SCSI_DEVICE_OPTICAL,
};
#define CDROM_RAW_SECTORSIZE    2352
#define CDROM_COMMON_SECTORSIZE 2048
#define MAX_SCSI_COMMAND  0xff
#define SCSI_COMMAND_HANDLER(x) static byte x(SCSI_DEVICE *dev, const byte *cdb)
#if DEBUG == 1
#define serial Serial2 // PA2 TX, PA3 RX
#define LOG(XX)      serial.print(XX)
#define LOGHEX(XX)   serial.print(XX, HEX)
#define LOGDEC(XX)   serial.print(XX, DEC)
#define LOGBIN(XX)   serial.print(XX, BIN)
#define LOGN(XX)     serial.println(XX)
#define LOGHEXN(XX)  serial.println(XX, HEX)
#define LOGDECN(XX)  serial.println(XX, DEC)
#define LOGBIN_N(XX) serial.println(XX, BIN)
#else
#define LOG(XX)       //serial.print(XX)
#define LOGHEX(XX)    //serial.print(XX, HEX)
#define LOGDEC(XX)    //serial.print(XX, DEC)
#define LOGBIN(XX)    //serial.print(XX, BIN)
#define LOGN(XX)      //serial.println(XX)
#define LOGHEXN(XX)   //serial.println(XX, HEX)
#define LOGDECN(XX)   //serial.println(XX, DEC)
#define LOGBIN_N(XX)  //serial.println(XX, BIN)
#endif
#define active   1
#define inactive 0
#define high 0
#define low 1
#define isHigh(XX) ((XX) == high)
#define isLow(XX) ((XX) != high)
#define ATN       PA8      // SCSI:ATN
#define BSY       PA9      // SCSI:BSY
#define ACK       PA10     // SCSI:ACK
#define RST       PA15     // SCSI:RST
#define MSG       PB3      // SCSI:MSG
#define SEL       PB4      // SCSI:SEL
#define CD        PB5      // SCSI:C/D
#define REQ       PB6      // SCSI:REQ
#define IO        PB7      // SCSI:I/O
#define LED       PC13     // LED
#define LED2      PB1      // Driven LED
#define IMAGE_SELECT1   PC14
#define IMAGE_SELECT2   PC15
#define PAREG GPIOA->regs
#define PBREG GPIOB->regs
#define PCREG GPIOC->regs
#define LED_ON()       PCREG->BSRR = 0x20000000; PBREG->BSRR = 0x00000002;
#define LED_OFF()      PCREG->BSRR = 0x00002000; PBREG->BSRR = 0x00020000;
#define PA(BIT)       (BIT)
#define PB(BIT)       (BIT+16)
#define GPIOREG(VPIN)     ((VPIN) >= 16 ? PBREG : PAREG)
#define BITMASK(VPIN)     (1 << ((VPIN) & 15))
#define vATN       PA(8)      // SCSI:ATN
#define vBSY       PA(9)      // SCSI:BSY
#define vACK       PA(10)     // SCSI:ACK
#define vRST       PA(15)     // SCSI:RST
#define vMSG       PB(3)      // SCSI:MSG
#define vSEL       PB(4)      // SCSI:SEL
#define vCD        PB(5)      // SCSI:C/D
#define vREQ       PB(6)      // SCSI:REQ
#define vIO        PB(7)      // SCSI:I/O
#define vSD_CS     PA(4)      // SDCARD:CS
#define SCSI_OUT(VPIN,ACTIVE) { GPIOREG(VPIN)->BSRR = BITMASK(VPIN) << ((ACTIVE) ? 16 : 0); }
#define SCSI_IN(VPIN) ((~GPIOREG(VPIN)->IDR >> (VPIN & 15)) & 1)
#define NOP(x) for(unsigned _nopcount = x; _nopcount; _nopcount--) { asm("NOP"); }
#define SCSI_BUS_SETTLE() NOP(30);                            // spec 400ns ours ~420us
#define SCSI_DATA_RELEASE() NOP(30);                          // spec 400ns ours ~420us
#define SCSI_HOLD_TIME() asm("NOP"); asm("NOP"); asm("NOP");  // spec 45ns ours ~42ns
#define SCSI_DESKEW() // asm("NOP"); asm("NOP"); asm("NOP");     // spec 45ns ours ~42ns
#define SCSI_CABLE_SKEW() // asm("NOP");                         // spec 10ns ours ~14ns
#define SCSI_RESET_HOLD() asm("NOP"); asm("NOP");             // spec 25ns ours ~28ns
#define SCSI_DISCONNECTION_DELAY() NOP(15);                   // spec 200ns ours ~210ns
#define SCSIPHASEMASK(MSGACTIVE, CDACTIVE, IOACTIVE) ((BITMASK(vMSG)<<((MSGACTIVE)?16:0)) | (BITMASK(vCD)<<((CDACTIVE)?16:0)) | (BITMASK(vIO)<<((IOACTIVE)?16:0)))
#define SCSI_PHASE_DATAOUT SCSIPHASEMASK(inactive, inactive, inactive)
#define SCSI_PHASE_DATAIN SCSIPHASEMASK(inactive, inactive, active)
#define SCSI_PHASE_COMMAND SCSIPHASEMASK(inactive, active, inactive)
#define SCSI_PHASE_STATUS SCSIPHASEMASK(inactive, active, active)
#define SCSI_PHASE_MESSAGEOUT SCSIPHASEMASK(active, active, inactive)
#define SCSI_PHASE_MESSAGEIN SCSIPHASEMASK(active, active, active)
#define SCSI_PHASE_CHANGE(MASK) { PBREG->BSRR = (MASK); }
static const uint32_t scsiDbOutputRegOr = 0x55150011;
static const uint32_t scsiDbInputOutputAnd = 0x00C0FFCC;
#define SCSI_DB_OUTPUT() { PBREG->MODER = (PBREG->MODER & scsiDbInputOutputAnd) | scsiDbOutputRegOr; }
#define SCSI_DB_INPUT()  { PBREG->MODER = (PBREG->MODER & scsiDbInputOutputAnd); }
#if XCVR == 1
#define TR_TARGET        PA0   // Target Transceiver Control Pin
#define TR_DBP           PA1   // Data Pins Transceiver Control Pin
#define TR_INITIATOR     PA2   // Initiator Transciever Control Pin
#define vTR_TARGET       PA(0) // Target Transceiver Control Pin
#define vTR_DBP          PA(1) // Data Pins Transceiver Control Pin
#define vTR_INITIATOR    PA(2) // Initiator Transciever Control Pin
#define TR_INPUT 1
#define TR_OUTPUT 0
#define TRANSCEIVER_IO_SET(VPIN,TR_INPUT) { GPIOREG(VPIN)->BSRR = BITMASK(VPIN) << ((TR_INPUT) ? 16 : 0); }
static const uint32_t SCSI_TARGET_PORTA_AND = 0xFFF3FFFF;  // Sets input mode when AND-ed against MODER
static const uint32_t SCSI_TARGET_PORTA_OR = 0x00040000;  // Sets output mode when AND+OR against MODER
static const uint32_t SCSI_TARGET_PORTB_AND = 0xFFFF033F;  // Sets input mode when AND-ed against MODER
static const uint32_t SCSI_TARGET_PORTB_OR = 0x00005440;  // Sets output mode when AND+OR against MODER
#define SCSI_BSY_ACTIVE()      { PAREG->MODER = (PAREG->MODER & SCSI_TARGET_PORTA_AND) | SCSI_TARGET_PORTA_OR; PBREG->MODER = (PBREG->MODER & SCSI_TARGET_PORTB_AND) | SCSI_TARGET_PORTB_OR; SCSI_OUT(vBSY, active) }
#define SCSI_TARGET_INACTIVE() { PAREG->MODER = (PAREG->MODER & SCSI_TARGET_PORTA_AND); PBREG->MODER = (PBREG->MODER & SCSI_TARGET_PORTB_AND); TRANSCEIVER_IO_SET(vTR_TARGET,TR_INPUT); }
#define SCSI_TARGET_ACTIVE()   { PAREG->MODER = (PAREG->MODER & SCSI_TARGET_PORTA_AND) | SCSI_TARGET_PORTA_OR; PBREG->MODER = (PBREG->MODER & SCSI_TARGET_PORTB_AND) | SCSI_TARGET_PORTB_OR; }
#else
#define SCSI_BSY_ACTIVE()      { pinMode(BSY, OUTPUT_OPEN_DRAIN); SCSI_OUT(vBSY,  active) }
#define SCSI_TARGET_INACTIVE() { SCSI_OUT(vREQ,inactive); SCSI_PHASE_CHANGE(SCSI_PHASE_DATAOUT); SCSI_OUT(vBSY,inactive); pinMode(BSY, INPUT); }
#define SCSI_TARGET_ACTIVE()   { }
#endif
#define HDIMG_ID_POS  2                 // Position to embed ID number
#define HDIMG_LUN_POS 3                 // Position to embed LUN numbers
#define HDIMG_BLK_POS 5                 // Position to embed block size numbers
#define MAX_FILE_PATH 64                // Maximum file name length
static uint32_t genBSRR(uint32_t data) {
  uint8_t masks[] = {0UL, 1UL, 2UL, 3UL, 4UL, 5UL, 6UL, 7UL};
  uint8_t positions[] = {8UL, 9UL, 10UL, 2UL, 12UL, 13UL, 14UL, 15UL};
  uint8_t dbpPosition = 0UL;
  int reqPosition = 6;
  uint8_t bitsAsserted = 0;
  uint32_t output = 0x00000000;
  for (int i = 0; i < 8; i++) {
    if (data & (0x1 << masks[i])) {
      output |= 0x1 << (positions[i] + 16);
      bitsAsserted++;
    } else {
      output |= (0x1 << positions[i]);
    }
  }
  if (bitsAsserted % 2 == 0) {
    output |= 0x01 << (dbpPosition + 16);
  } else {
    output |= 0x01 << dbpPosition;
  }
  if (reqPosition >= 0) {
    output |= 0x01 << reqPosition;
  }
  return output;
}
uint32_t db_bsrr[256];
#define PARITY(DB) (db_bsrr[DB]&1)
#define READ_DATA_BUS() (byte)((~(uint32_t)GPIOB->regs->IDR)>>8)
struct SCSI_INQUIRY_DATA
{
  union
  {
  struct {
    byte peripheral_device_type:5;
    byte peripheral_qualifier:3;
    byte reserved_byte2:7;
    byte rmb:1;
    byte ansi_version:3;
    byte always_zero_byte3:5;
    byte response_format:4;
    byte reserved_byte4:2;
    byte tiop:1;
    byte always_zero_byte4:1;
    byte additional_length;
    byte reserved_byte5;
    byte reserved_byte6;
    byte sync:1;
    byte always_zero_byte7_more:4;
    byte always_zero_byte7:3;
    char vendor[8];
    char product[16];
    char revision[4];
    byte release;
    char revision_date[10];
  };
  byte raw[64];
  };
};
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

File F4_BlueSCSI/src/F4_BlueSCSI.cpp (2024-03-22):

/*  
 *  F4 BlueSCSI
 *  Copyright (c) 2021  Eric Helgeson, Tech by Androda, LLC
 *  
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
 * This file incorporates work covered by the following copyright and  
 * permission notice:  
 *  
 *     Copyright (c) 2019 komatsu   
 *  
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
 *     THE SOFTWARE IS PROVIDED "AS IS" AND THE AUTHOR DISCLAIMS ALL  
 *     WARRANTIES WITH REGARD TO THIS SOFTWARE INCLUDING ALL IMPLIED  
 *     WARRANTIES OF MERCHANTABILITY AND FITNESS. IN NO EVENT SHALL THE  
 *     AUTHOR BE LIABLE FOR ANY SPECIAL, DIRECT, INDIRECT, OR  
 *     CONSEQUENTIAL DAMAGES OR ANY DAMAGES WHATSOEVER RESULTING FROM LOSS  
 *     OF USE, DATA OR PROFITS, WHETHER IN AN ACTION OF CONTRACT,  
 *     NEGLIGENCE OR OTHER TORTIOUS ACTION, ARISING OUT OF OR IN  
 *     CONNECTION WITH THE USE OR PERFORMANCE OF THIS SOFTWARE.  
 */
 
#pragma GCC diagnostic warning "-fpermissive"

#include <Arduino.h> // For Platform.IO
#include <SdFat.h>
#include <setjmp.h>
#include <libmaple/exti.h>

#define DEBUG            0      // 0:No debug information output
                                // 1: Debug information output to USB Serial
                                // 2: Debug information output to LOG.txt (slow)
#define XCVR             0      // 0 for standard mode
                                // 1 for transceiver hardware


#ifndef MCU_STM32F401CC
#define MCV "F4"
#else
#define MCV "F4Lite"
#endif

#define VDS "2022-12-20"

// Log File
#if XCVR == 1
#define VERSION "1.1-" VDS "-XCVR-" MCV
#else
#define VERSION "1.1-" VDS "-" MCV
#endif
#define LOG_FILENAME "LOG.txt"

#include "BlueSCSI.h"
#include "scsi_cmds.h"
#include "scsi_sense.h"
#include "scsi_status.h"
#include "scsi_mode.h"

#ifdef USE_STM32_DMA
#warning "warning USE_STM32_DMA"
#endif

// SDFAT
SdFs SD;
FsFile LOG_FILE;

volatile bool m_isBusReset = false;   // Bus reset
volatile bool m_resetJmp = false;     // Call longjmp on reset
jmp_buf       m_resetJmpBuf;

byte          scsi_id_mask;              // Mask list of responding SCSI IDs
byte          m_id;                      // Currently responding SCSI-ID
byte          m_lun;                     // Logical unit number currently responding
byte          m_sts;                     // Status byte
byte          m_msg;                     // Message bytes
byte          m_buf[MAX_BLOCKSIZE];      // General purpose buffer
byte          m_scsi_buf[SCSI_BUF_SIZE]; // Buffer for SCSI READ/WRITE Buffer
unsigned      m_scsi_buf_size = 0;
byte          m_msb[256];                // Command storage bytes
SCSI_DEVICE scsi_device_list[NUM_SCSIID][NUM_SCSILUN]; // Maximum number
SCSI_INQUIRY_DATA default_hdd, default_optical;

// Enables SCSI IDs to be representing as LUNs on SCSI ID 0 
// This supports a specific case for the Atari MegaSTE internal SCSI adapter
bool megaste_mode = false;

// function table
byte (*scsi_command_table[MAX_SCSI_COMMAND])(SCSI_DEVICE *dev, const byte *cdb);

// scsi command functions
SCSI_COMMAND_HANDLER(onUnimplemented);
SCSI_COMMAND_HANDLER(onNOP);

SCSI_COMMAND_HANDLER(onRequestSense);
SCSI_COMMAND_HANDLER(onRead6);
SCSI_COMMAND_HANDLER(onRead10);
SCSI_COMMAND_HANDLER(onWrite6);
SCSI_COMMAND_HANDLER(onWrite10);
SCSI_COMMAND_HANDLER(onInquiry);
SCSI_COMMAND_HANDLER(onReadCapacity);
SCSI_COMMAND_HANDLER(onModeSense);
SCSI_COMMAND_HANDLER(onModeSelect);
SCSI_COMMAND_HANDLER(onVerify);
SCSI_COMMAND_HANDLER(onReadBuffer);
SCSI_COMMAND_HANDLER(onWriteBuffer);
SCSI_COMMAND_HANDLER(onTestUnitReady);
SCSI_COMMAND_HANDLER(onReZeroUnit);
SCSI_COMMAND_HANDLER(onSendDiagnostic);
SCSI_COMMAND_HANDLER(onReadDefectData);
SCSI_COMMAND_HANDLER(onReadTOC);
SCSI_COMMAND_HANDLER(onReadDVDStructure);
SCSI_COMMAND_HANDLER(onReadDiscInformation);

static uint32_t MSFtoLBA(const byte *msf);
static void LBAtoMSF(const uint32_t lba, byte *msf);

static void flashError(const unsigned error);
void onBusReset(void);
void initFileLog(int);
void finalizeFileLog(void);
void findDriveImages(FsFile root);

/*
 * IO read.
 */
inline byte readIO(void)
{
  // Port input data register
  uint32_t ret = GPIOB->regs->IDR;
  byte bret = (byte)~(((ret >> 8) & 0b11110111) | ((ret & 0x00000004) << 1));
#if READ_PARITY_CHECK
  if((db_bsrr[bret]^ret)&1)  // TODO fix parity calculation
    m_sts |= 0x01; // parity error
#endif

  return bret;
}

// If config file exists, read the first three lines and copy the contents.
// File must be well formed or you will get junk in the SCSI Vendor fields.
void readSCSIDeviceConfig(SCSI_DEVICE *dev) {
  FsFile config_file = SD.open("scsi-config.txt", O_RDONLY);
  if (!config_file.isOpen()) {
    return;
  }
  SCSI_INQUIRY_DATA *iq = dev->inquiry_block;

  char vendor[9];
  memset(vendor, 0, sizeof(vendor));
  config_file.readBytes(vendor, sizeof(vendor));
  LOG_FILE.print("SCSI VENDOR: ");
  LOG_FILE.println(vendor);
  memcpy(&iq->vendor, vendor, 8);

  char product[17];
  memset(product, 0, sizeof(product));
  config_file.readBytes(product, sizeof(product));
  LOG_FILE.print("SCSI PRODUCT: ");
  LOG_FILE.println(product);
  memcpy(&iq->product, product, 16);

  char version[5];
  memset(version, 0, sizeof(version));
  config_file.readBytes(version, sizeof(version));
  LOG_FILE.print("SCSI VERSION: ");
  LOG_FILE.println(version);
  memcpy(&iq->revision, version, 4);
  config_file.close();
}

// read SD information and print to logfile
void readSDCardInfo()
{
  cid_t sd_cid;

  if(SD.card()->readCID(&sd_cid))
  {
    LOG_FILE.print("Sd MID:");
    LOG_FILE.print(sd_cid.mid, 16);
    LOG_FILE.print(" OID:");
    LOG_FILE.print(sd_cid.oid[0]);
    LOG_FILE.println(sd_cid.oid[1]);

    LOG_FILE.print("Sd Name:");
    LOG_FILE.print(sd_cid.pnm[0]);
    LOG_FILE.print(sd_cid.pnm[1]);
    LOG_FILE.print(sd_cid.pnm[2]);
    LOG_FILE.print(sd_cid.pnm[3]);
    LOG_FILE.println(sd_cid.pnm[4]);

    LOG_FILE.print("Sd Date:");
    LOG_FILE.print(sd_cid.mdtMonth());
    LOG_FILE.print("/");
    LOG_FILE.println(sd_cid.mdtYear());

    LOG_FILE.print("Sd Serial:");
    LOG_FILE.println(sd_cid.psn());
    LOG_FILE.sync();
  }
}

bool VerifyISOPVD(SCSI_DEVICE *dev, unsigned sector_size, bool mode2)
{ 
  int seek = 16 * sector_size;
  if(sector_size > CDROM_COMMON_SECTORSIZE) seek += 16;
  if(mode2) seek += 8;
  bool ret = false;

  dev->m_file->seekSet(seek);
  dev->m_file->read(m_buf, 2048);

  ret = ((m_buf[0] == 1 && !strncmp((char *)&m_buf[1], "CD001", 5) && m_buf[6] == 1) ||
        (m_buf[8] == 1 && !strncmp((char *)&m_buf[9], "CDROM", 5) && m_buf[14] == 1));

  dev->m_file->rewind();
  return ret;
}

/*
 * Open HDD image file
 */

bool hddimageOpen(SCSI_DEVICE *dev, FsFile *file,int id,int lun,int blocksize)
{
  dev->m_fileSize= 0;
  dev->m_sector_offset = 0;
  dev->m_blocksize = blocksize;
  dev->m_rawblocksize = blocksize;
  dev->m_file = file;
  if(!dev->m_file->isOpen()) { goto failed; }

  dev->m_fileSize = dev->m_file->size();
  
  if(dev->m_fileSize < 1) {
    LOG_FILE.println(" - file is 0 bytes, can not use.");
    goto failed;
  }
  if(!dev->m_file->isContiguous())
  {
    LOG_FILE.println(" - file is fragmented, see https://github.com/erichelgeson/BlueSCSI/wiki/Image-File-Fragmentation");
  }

  if(dev->m_type == SCSI_DEVICE_OPTICAL) {
    LOG_FILE.print(" CDROM");
    dev->m_blocksize = CDROM_COMMON_SECTORSIZE;

    // Borrowed from PCEM
    if(VerifyISOPVD(dev, CDROM_COMMON_SECTORSIZE, false)) {
      dev->m_rawblocksize = CDROM_COMMON_SECTORSIZE;
      dev->m_mode2 = false;
    } else if(VerifyISOPVD(dev, CDROM_RAW_SECTORSIZE, false)) {
      dev->m_rawblocksize = CDROM_RAW_SECTORSIZE;
      dev->m_mode2 = false;
      dev->m_raw = true;
      dev->m_sector_offset = 16;
    } else if(VerifyISOPVD(dev, 2336, true)) {
      dev->m_rawblocksize = 2336;
      dev->m_mode2 = true;
    } else if(VerifyISOPVD(dev, CDROM_RAW_SECTORSIZE, true)) {
      dev->m_rawblocksize = CDROM_RAW_SECTORSIZE;
      dev->m_mode2 = true;
      dev->m_raw = true;
      dev->m_sector_offset = 24;
    } else {
      // Last ditch effort
      // size must be less than 700MB
      if(dev->m_fileSize > 912579600) {
        goto failed;
      }

      dev->m_raw = true;

      if(!(dev->m_fileSize % CDROM_COMMON_SECTORSIZE)) {
        // try a multiple of 2048
        dev->m_blocksize = CDROM_COMMON_SECTORSIZE;
        dev->m_rawblocksize = CDROM_COMMON_SECTORSIZE;
      } else {
        // I give up!
        LOG_FILE.println(" InvalidISO");
        goto failed;
      }
    }
  } else {
    LOG_FILE.print(" HDD");
  }
  dev->m_blockcount = dev->m_fileSize / dev->m_blocksize;

  // check blocksize dummy file
  LOG_FILE.print(" / ");
  LOG_FILE.print(dev->m_fileSize);
  LOG_FILE.print("bytes / ");
  LOG_FILE.print(dev->m_fileSize / 1024);
  LOG_FILE.print("KiB / ");
  LOG_FILE.print(dev->m_fileSize / 1024 / 1024);
  LOG_FILE.println("MiB");

  if(dev->m_type == SCSI_DEVICE_OPTICAL) {
    LOG_FILE.print(" MODE2:");LOG_FILE.print(dev->m_mode2);
    LOG_FILE.print(" BlockSize:");LOG_FILE.println(dev->m_rawblocksize);
  }
  return true; // File opened

failed:    
  
  dev->m_file->close();
  dev->m_fileSize = dev->m_blocksize = 0; // no file
  delete dev->m_file;
  dev->m_file = NULL;
  return false;
}

/*
 * Initialization.
 *  Initialize the bus and set the PIN orientation
 */
void setup()
{
  // Setup BSRR table
  for (unsigned i = 0; i <= 255; i++) {
    db_bsrr[i] = genBSRR(i);
  }

  // Default all SCSI command handlers to onUnimplemented
  for(unsigned i = 0; i < MAX_SCSI_COMMAND; i++)
  {
    scsi_command_table[i] = onUnimplemented;
  }

  // zero all SCSI device structs
  for(unsigned id = 0; id < NUM_SCSIID; id++)
  {
    for(unsigned lun = 0; lun < NUM_SCSILUN; lun++)
    {
      memset(&scsi_device_list[id][lun], 0, sizeof(SCSI_DEVICE));
    }
  }

  // SCSI commands that just need to return ok
  scsi_command_table[SCSI_FORMAT_UNIT4] = onNOP;
  scsi_command_table[SCSI_FORMAT_UNIT6] = onNOP;
  scsi_command_table[SCSI_REASSIGN_BLOCKS] = onNOP;
  scsi_command_table[SCSI_SEEK6] = onNOP;
  scsi_command_table[SCSI_SEEK10] = onNOP;
  scsi_command_table[SCSI_START_STOP_UNIT] = onNOP;
  scsi_command_table[SCSI_PREVENT_ALLOW_REMOVAL] = onNOP;
  scsi_command_table[SCSI_RELEASE] = onNOP;
  scsi_command_table[SCSI_RESERVE] = onNOP;
  scsi_command_table[SCSI_TEST_UNIT_READY] = onNOP;
  
  // SCSI commands that have handlers
  scsi_command_table[SCSI_REZERO_UNIT] = onReZeroUnit;
  scsi_command_table[SCSI_REQUEST_SENSE] = onRequestSense;
  scsi_command_table[SCSI_READ6] = onRead6;
  scsi_command_table[SCSI_READ10] = onRead10;
  scsi_command_table[SCSI_WRITE6] = onWrite6;
  scsi_command_table[SCSI_WRITE10] = onWrite10;
  scsi_command_table[SCSI_INQUIRY] = onInquiry;
  scsi_command_table[SCSI_READ_CAPACITY] = onReadCapacity;
  scsi_command_table[SCSI_MODE_SENSE6] =  onModeSense;
  scsi_command_table[SCSI_MODE_SENSE10] = onModeSense;
  scsi_command_table[SCSI_MODE_SELECT6] = onModeSelect;
  scsi_command_table[SCSI_MODE_SELECT10] = onModeSelect;
  scsi_command_table[SCSI_VERIFY10] = onVerify;
  scsi_command_table[SCSI_READ_BUFFER] = onReadBuffer;
  scsi_command_table[SCSI_WRITE_BUFFER] = onWriteBuffer;
  scsi_command_table[SCSI_SEND_DIAG] = onSendDiagnostic;
  scsi_command_table[SCSI_READ_DEFECT_DATA] = onReadDefectData;
  scsi_command_table[SCSI_READ_TOC] = onReadTOC;
  scsi_command_table[SCSI_READ_DVD_STRUCTURE] = onReadDVDStructure;
  scsi_command_table[SCSI_READ_DISC_INFORMATION] = onReadDiscInformation;

  // clear and initialize default inquiry blocks
  // default SCSI HDD
  memset(&default_hdd, 0, sizeof(default_hdd));
  default_hdd.ansi_version = 1;
  default_hdd.response_format = 1;
  default_hdd.additional_length = 31;
  memcpy(&default_hdd.vendor, "QUANTUM", 7);
  memcpy(&default_hdd.product, "F4 BlueSCSI", 11);
  memcpy(&default_hdd.revision, "1.0", 3);

  // default SCSI CDROM
  memset(&default_optical, 0, sizeof(default_optical));
  default_optical.peripheral_device_type = 5;
  default_optical.rmb = 1;
  default_optical.ansi_version = 1;
  default_optical.response_format = 1;
  default_optical.additional_length = 42;
  default_optical.sync = 1;
  memcpy(&default_optical.vendor, "BLUESCSI", 8);
  memcpy(&default_optical.product, "CD-ROM CDU-55S", 14);
  memcpy(&default_optical.revision, "1.9a", 4);
  default_optical.release = 0x20;
  memcpy(&default_optical.revision_date, "1995", 4);

  // Serial initialization
#if DEBUG == 1
  serial.begin(9600);
  // If using a USB->TTL monitor instead of USB serial monitor - you can uncomment this.
  //while (!Serial);
#endif

  // PIN initialization
  pinMode(LED, OUTPUT_OPEN_DRAIN);
  pinMode(LED2, OUTPUT);
  
  // Image Set Select Init
  pinMode(IMAGE_SELECT1, INPUT_PULLUP);
  pinMode(IMAGE_SELECT2, INPUT_PULLUP);
  pinMode(IMAGE_SELECT1, INPUT);
  pinMode(IMAGE_SELECT2, INPUT);
  int image_file_set = ((digitalRead(IMAGE_SELECT1) == LOW) ? 1 : 0) | ((digitalRead(IMAGE_SELECT2) == LOW) ? 2 : 0);
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
void loop() 
{
#if XCVR == 1
  // Reset all DB and Target pins, switch transceivers to input
  // Precaution against bugs or jumps which don't clean up properly
  SCSI_DB_INPUT();
  TRANSCEIVER_IO_SET(vTR_DBP,TR_INPUT)
  SCSI_TARGET_INACTIVE();
  TRANSCEIVER_IO_SET(vTR_TARGET,TR_INPUT)
  // Reset target state bits (BSY, MSG, CD, REQ, IO)
  GPIOB->regs->BSRR = 0x000000E8; // MSG, CD, REQ, IO
  GPIOA->regs->BSRR = 0x00000200; // BSY
  TRANSCEIVER_IO_SET(vTR_INITIATOR,TR_INPUT)
#endif

  //int msg = 0;
  m_msg = 0;
  m_lun = 0xff;
  SCSI_DEVICE *dev = (SCSI_DEVICE *)0; // HDD image for current SCSI-ID, LUN

  do {} while( SCSI_IN(vBSY) || !SCSI_IN(vSEL) || SCSI_IN(vRST));
  //do {} while( !SCSI_IN(vBSY) || SCSI_IN(vRST));
  // We're in ARBITRATION
  //LOG(" A:"); LOGHEX(readIO()); LOG(" ");
  
  //do {} while( SCSI_IN(vBSY) || !SCSI_IN(vSEL) || SCSI_IN(vRST));
  //LOG(" S:"); LOGHEX(readIO()); LOG(" ");
  // We're in SELECTION
  
  byte scsiid = readIO() & scsi_id_mask;
  if(SCSI_IN(vIO) || (scsiid) == 0) {
    delayMicroseconds(1);
    return;
  }
  // We've been selected

#if XCVR == 1
  TRANSCEIVER_IO_SET(vTR_TARGET,TR_OUTPUT);
#endif
  SCSI_TARGET_ACTIVE()  // (BSY), REQ, MSG, CD, IO output turned on

  // Set BSY to-when selected
  SCSI_BSY_ACTIVE();     // Turn only BSY output ON, ACTIVE

  // Wait until SEL becomes inactive
  while(isHigh(digitalRead(SEL))) {}
  
  // Ask for a TARGET-ID to respond
  m_id = 31 - __builtin_clz(scsiid);

  m_isBusReset = false;
  if (setjmp(m_resetJmpBuf) == 1) {
    LOGN("Reset, going to BusFree");
    goto BusFree;
  }
  enableResetJmp();
  
  // In SCSI-2 this is mandatory, but in SCSI-1 it's optional 
  if(isHigh(digitalRead(ATN))) {
    SCSI_PHASE_CHANGE(SCSI_PHASE_MESSAGEOUT);
    // Bus settle delay 400ns. Following code was measured at 350ns before REQ asserted. Added another 50ns. STM32F103.
    SCSI_PHASE_CHANGE(SCSI_PHASE_MESSAGEOUT);// 28ns delay STM32F103
    SCSI_PHASE_CHANGE(SCSI_PHASE_MESSAGEOUT);// 28ns delay STM32F103
    bool syncenable = false;
    int syncperiod = 50;
    int syncoffset = 0;
    int msc = 0;
    while(isHigh(digitalRead(ATN)) && msc < 255) {
      m_msb[msc++] = readHandshake();
    }
    for(int i = 0; i < msc; i++) {
      // ABORT
      if (m_msb[i] == 0x06) {
        goto BusFree;
      }
      // BUS DEVICE RESET
      if (m_msb[i] == 0x0C) {
        syncoffset = 0;
        goto BusFree;
      }
      // IDENTIFY
      if (m_msb[i] >= 0x80) {
        m_lun = m_msb[i] & 0x1f;
      }
      // Extended message
      if (m_msb[i] == 0x01) {
        // Check only when synchronous transfer is possible
        if (!syncenable || m_msb[i + 2] != 0x01) {
          MsgIn2(0x07);
          break;
        }
        // Transfer period factor(50 x 4 = Limited to 200ns)
        syncperiod = m_msb[i + 3];
        if (syncperiod > 50) {
          syncperiod = 50;
        }
        // REQ/ACK offset(Limited to 16)
        syncoffset = m_msb[i + 4];
        if (syncoffset > 16) {
          syncoffset = 16;
        }
        // STDR response message generation
        MsgIn2(0x01);
        MsgIn2(0x03);
        MsgIn2(0x01);
        MsgIn2(syncperiod);
        MsgIn2(syncoffset);
        break;
      }
    }
  }

  LOG("CMD:");
  SCSI_PHASE_CHANGE(SCSI_PHASE_COMMAND);
  // Bus settle delay 400ns. The following code was measured at 20ns before REQ asserted. Added another 380ns. STM32F103.
  asm("nop;nop;nop;nop;nop;nop;nop;nop");// This asm causes some code reodering, which adds 270ns, plus 8 nop cycles for an additional 110ns. STM32F103
  int len;
  byte cmd[20];

  cmd[0] = readHandshake();
  // Atari ST ICD extension support
  // It sends a 0x1F as a indicator there is a 
  // proper full size SCSI command byte to follow
  // so just read it and re-read it again to get the
  // real command byte
  if(cmd[0] == SCSI_ICD_EXTENDED_CMD) { cmd[0] = readHandshake(); }

  LOGHEX(cmd[0]);
  // Command length selection, reception
  len = cdb_len_lookup[cmd[0]];
  cmd[1] = readHandshake(); LOG(":");LOGHEX(cmd[1]);
  cmd[2] = readHandshake(); LOG(":");LOGHEX(cmd[2]);
  cmd[3] = readHandshake(); LOG(":");LOGHEX(cmd[3]);
  cmd[4] = readHandshake(); LOG(":");LOGHEX(cmd[4]);
  cmd[5] = readHandshake(); LOG(":");LOGHEX(cmd[5]);
  // Receive the remaining commands
  for(int i = 6; i < len; i++ ) {
    cmd[i] = readHandshake();
    LOG(":");
    LOGHEX(cmd[i]);
  }
  // LUN confirmation
  // if it wasn't set in the IDENTIFY then grab it from the CDB
  if(m_lun > MAX_SCSILUN)
  {
    m_lun = (cmd[1] & 0xe0) >> 5;
    if(megaste_mode)
    {
      // if this mode is enabled we are going to substitute all SCSI IDs as LUNs on ID0
      // this is because the MegaSTE internal adapter only supports ID0. This lets multiple 
      // devices still be used

      LOG(" MSTE MODE ID:"); LOG(m_id); LOG(" LUN:"); LOG(m_lun);
      if(scsi_device_list[m_lun][0].m_fileSize)
      {
        m_id = m_lun;
        m_lun = 0;
        LOG(" => ID:"); LOG(m_id); LOG(" LUN:"); LOG(m_lun); LOG(" ");
      }
    }
  }

  LOG(":ID ");
  LOG(m_id);
  LOG(":LUN ");
  LOG(m_lun);
  LOG(" ");

  // HDD Image selection
  if(m_lun >= NUM_SCSILUN)
  {
    m_sts = SCSI_STATUS_GOOD;

    // REQUEST SENSE and INQUIRY are handled different with invalid LUNs
    if(cmd[0] == SCSI_INQUIRY)
    {
      // Special INQUIRY handling for invalid LUNs
      LOGN("onInquiry - InvalidLUN");
      dev = &(scsi_device_list[m_id][0]);

      byte temp = dev->inquiry_block->raw[0];

      // If the LUN is invalid byte 0 of inquiry block needs to be 7fh
      dev->inquiry_block->raw[0] = 0x7f;

      // only write back what was asked for
      writeDataPhase(cmd[4], dev->inquiry_block->raw);

      // return it back to normal if it was altered
      dev->inquiry_block->raw[0] = temp;
    }
    else if(cmd[0] == SCSI_REQUEST_SENSE)
    {
      byte buf[18] = {
        0x70,   //CheckCondition
        0,      //Segment number
        SCSI_SENSE_ILLEGAL_REQUEST,   //Sense key
        0, 0, 0, 0,  //information
        10,   //Additional data length
        0, 0, 0, 0, // command specific information bytes
        (byte)(SCSI_ASC_LOGICAL_UNIT_NOT_SUPPORTED >> 8),
        (byte)SCSI_ASC_LOGICAL_UNIT_NOT_SUPPORTED,
        0, 0, 0, 0,
      };
      writeDataPhase(cmd[4] < 18 ? cmd[4] : 18, buf);      
    }
    else
    {    
      m_sts = SCSI_STATUS_CHECK_CONDITION;
    }

    goto Status;
  }

  dev = &(scsi_device_list[m_id][m_lun]);
  if(!dev->m_file)
  {
    dev->m_senseKey = SCSI_SENSE_ILLEGAL_REQUEST;
    dev->m_additional_sense_code = SCSI_ASC_LOGICAL_UNIT_NOT_SUPPORTED;
    m_sts = SCSI_STATUS_CHECK_CONDITION;
    goto Status;
  }

  LED_ON();
  m_sts = scsi_command_table[cmd[0]](dev, cmd);
  LED_OFF();

Status:
  LOG(" STS:"); LOGHEX(m_sts);
  SCSI_PHASE_CHANGE(SCSI_PHASE_STATUS);
  // Bus settle delay 400ns built in to writeHandshake
  writeHandshake(m_sts);

  LOG(" MI:"); LOGHEX(m_msg);
  SCSI_PHASE_CHANGE(SCSI_PHASE_MESSAGEIN);
  // Bus settle delay 400ns built in to writeHandshake
  writeHandshake(m_msg);

BusFree:
  LOGN(" BF ");
  m_isBusReset = false;
  //SCSI_OUT(vREQ,inactive) // gpio_write(REQ, low);
  //SCSI_OUT(vMSG,inactive) // gpio_write(MSG, low);
  //SCSI_OUT(vCD ,inactive) // gpio_write(CD, low);
  //SCSI_OUT(vIO ,inactive) // gpio_write(IO, low);
  //SCSI_OUT(vBSY,inactive)
  SCSI_TARGET_INACTIVE() // Turn off BSY, REQ, MSG, CD, IO output
#if XCVR == 1
  TRANSCEIVER_IO_SET(vTR_TARGET,TR_INPUT);
  // Something in code linked after this function is performing better with a +4 alignment.
  // Adding this nop is causing the next function (_GLOBAL__sub_I_SD) to have an address with a last digit of 0x4.
  // Last digit of 0xc also works.
  // This affects both with and without XCVR, currently without XCVR doesn't need any padding.
  // Until the culprit can be tracked down and fixed, it may be necessary to do manual adjustment.
  asm("nop.w");
#endif
}

static byte onUnimplemented(SCSI_DEVICE *dev, const byte *cdb)
{
  // does nothing!
  LOG("Unimplemented SCSI command: ");
  LOGHEXN(cdb[0]);

  dev->m_senseKey = SCSI_SENSE_ILLEGAL_REQUEST;
  dev->m_additional_sense_code = SCSI_ASC_INVALID_OPERATION_CODE;
  return SCSI_STATUS_CHECK_CONDITION;
}

static byte onNOP(SCSI_DEVICE *dev, const byte *cdb)
{
  dev->m_senseKey = 0;
  dev->m_additional_sense_code = 0;
  return SCSI_STATUS_GOOD;
}

/*
 * INQUIRY command processing.
 */
byte onInquiry(SCSI_DEVICE *dev, const byte *cdb)
{
  writeDataPhase(cdb[4] < 47 ? cdb[4] : 47, dev->inquiry_block->raw);
  return SCSI_STATUS_GOOD;
}
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

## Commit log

2021-11-11 Remove parent bluescsi files
    [BlueSCSI-1.0-b.stl, BlueSCSI-1.0-b_V2.stl, bluepill_scsi.kicad_pcb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]
2022-02-22 Various fixes for VAXstation
    [F4_BlueSCSI.ino]
2022-02-22 Minor white space fixes. Snapshot to VERSION
    [F4_BlueSCSI.ino]
2022-04-06 Hardware Release, in KiCAD V6 format
    CC BY-NC-SA 4.0 licensed hardware release.
    Note that these are all slightly tweaked versions of the ones currently for sale, and as such have not been produced for testing.
    [F4Lite_THTV1-B_Cu.gbr, F4Lite_THTV1-B_Mask.gbr, F4Lite_THTV1-B_Paste.gbr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]
2022-04-07 Fix filename
    Not sure where this came from, that filename is from an ancient prototype
2022-04-15 Squashed commit of the following:
    commit 76483ff815e1e442cda9677f54d5c8be8428723f
    Author: androda <androda@users.noreply.github.com>
    Date: Fri Apr 15 06:45:37 2022 -0600
    Add HW
    commit 6bc545ae7fe749063ec50225f4415f7c3cb96f44
    Author: androda <androda@users.noreply.github.com>
    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
    [MountingBracket.stl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]
2022-04-19 F4Lite THT V1.1
    Creative Commons Non-Commercial Licensed Version 1.1 of the F4Lite Desktop Design
    [F4Lite_THTV1_1-B_Cu.gbr, F4Lite_THTV1_1-B_Mask.gbr, F4Lite_THTV1_1-B_Paste.gbr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]
2022-05-03 Replace magic numbers with constants - thanks Jokker
    [F4_BlueSCSI.ino]
2022-06-01 Fix issue where log file would close when logging was enabled. Thanks @marcelv-3 https://github.com/erichelgeson/BlueSCSI/discussions/103#discussioncomment-2779471
    [F4_BlueSCSI.ino]
2022-06-19 Merge pull request #115 from mynameistroy/troy/function_table
    Switched to function table for SCSI commands
2022-06-21 Merge pull request #122 from erichelgeson/eric/spi
    We only need to test full and half speed spi
2022-06-27 Cleanup some stray command table definitions. Fix handling of dbd bit in onModeSense()
    [F4_BlueSCSI.ino]
2022-06-27 Merge pull request #134 from erichelgeson/eric/bugfixes
    Fix onReadCapacity calculation & Sense offset for Flexable Geometry
    [F4_BlueSCSI.ino]
2022-06-27 Merge pull request #135 from mynameistroy/troy/minorfixes
    minor fixes
    [BlueSCSI.h, F4_BlueSCSI.ino]
2022-06-27 Merge pull request #138 from erichelgeson/eric/vdrName
    Change product so vendor specific Quantum commands are not issued
    [F4_BlueSCSI.ino]
2022-07-01 PowerBook v1.1
    Quality of life change, moved the SD card slot so it's easier to use. Still fits in the standard drive footprint.
    [PBMountingBracket_THTV1_1.stl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]
2022-07-27 Switch GPIO Modes
    Many of the new F401 dev modules don't seem to work unless they're in push-pull mode. Thus, use open drain for F411 only.
2022-07-27 Update date, and customize log file version string
    Now printing out properly, F4 and F4Lite.
2022-07-28 LED on/off is around all commands, no need to have it here.
2022-07-28 out of phase error fixed, SGI Indy works now
    basic determination of arbitration
    [F4_BlueSCSI.ino]
2022-07-28 alternative sector size supported
    this let's .BIN files get used at the very least, maybe more depending
    on how some of the other optical formats look
    reverted a small SCSI phase change that causes problems
    [BlueSCSI.h, F4_BlueSCSI.ino]
2022-07-28 added missing set of raw sector size
    [F4_BlueSCSI.ino]
2022-09-20 MODE SELECT supports CDROM 512/2048 sector toggle
    CDROM devices return a DBD properly
    CDROM Error Mode Page has a default retry of 1
    More streamlining of debug logging
    [F4_BlueSCSI.ino]
2022-10-03 Updated designs, more SMD friendly
    Still CC BY-NC-SA 4.0
    [PBMountingBracket_THTV1_1.stl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]
2022-12-20 Merge pull request #183 from mynameistroy/troy/myst_fix
    Fix for incorrect response to READ_DVD_STRUCTURE
    [F4_BlueSCSI.ino]

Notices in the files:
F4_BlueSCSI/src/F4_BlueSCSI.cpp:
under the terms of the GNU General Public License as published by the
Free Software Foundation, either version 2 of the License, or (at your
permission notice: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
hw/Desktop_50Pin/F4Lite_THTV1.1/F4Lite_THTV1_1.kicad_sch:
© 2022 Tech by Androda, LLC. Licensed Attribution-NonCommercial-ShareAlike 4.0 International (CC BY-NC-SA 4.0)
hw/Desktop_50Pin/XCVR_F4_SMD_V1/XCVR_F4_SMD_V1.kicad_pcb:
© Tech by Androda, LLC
